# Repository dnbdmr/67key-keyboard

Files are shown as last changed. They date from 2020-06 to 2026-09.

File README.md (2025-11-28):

# A mechanical keyboard with a Thinkpad Trackpoint module installed

- Uses a trackpoint module from an old laptop keyboard. Some more details in hw/
- Uses Microchip SAMD21 MCU with TinyUSB
- Shift registers instead of key matrix

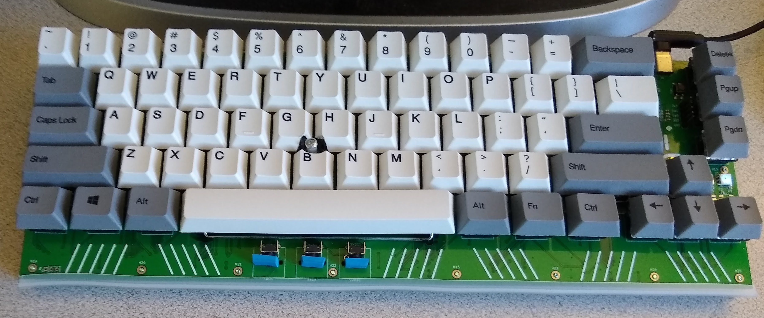
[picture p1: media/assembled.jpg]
Assembled picture


[Schematic](media/67keys-trackpoint.pdf)

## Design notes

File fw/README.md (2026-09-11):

# 67 Key keyboard with trackpoint

- Uses with uf2-samdx1 bootloader. Linker screipt offsetx by 0x2000. https://github.com/dnbdmr/uf2-samdx1

## TODO

- [ ] Finish keymap/layers
- [ ] Make tp reset non blocking?
- [ ] uf2: turn down brightness on rgbs
  tud\_descriptor\_string\_cb
- [ ] Merge spi master and matrix?
- [ ] Make force reset universal
- [ ] Turn off unused clocks? APB ADC. Whatever was started by uf2
- [ ] Figure out clean way to have keys do things outside of keymap
- [ ] Set up Fn lock
- [ ] Make menu/help, move to config.c?
- [ ] Intermittent wake up from sleep after putting computer to sleep.
- [ ] implement idle rate switch
- [x] Set serial number in descriptor? check uf2 source. add to
  wake up computer.
- [x] sends 3 reports whenever any key changes. problem?
- [x] limit scrolling to 1 at a time.
- [x] Check speedup of inlining millis(). Doesn't reallly work with externs.
  Cleared the dmb/irq around returning msticks, increased 108k->112kHz.
- [x] Implement debounce? Does happen occasionally.
- [x] tp reading and writing from ram stalls sometimes. dataAvailable not being
set? Done, set up timeout in tp\_getDataBit().
- [x] Wakeup from TP and spacebar working, with idle(1). Standby not working, must
set up low level interrupt and clocks. Linux not setting wakeup enabled by
default, works when changed. Must be hid only? Added udev rule from archwiki.
Changed HID portocol to keyboard in hid descriptor. Wakeup enabled without udev
rule
- [x] set up modifier reporting
- [x] set up system for leds
- [x] Delay a bit after middle mouse to make sure it's not a scroll. Do like tp
wired keyboard, only send middle button on release? Done, hardcoded dirtily.

## Power and Sleep

The trackpoint uses an external interrupt on the falling edge to clock in data.
There is also a line going straight to the space bar, set up to interrupt on a
low level. Level interrupts are asynchronout and can wake up from deep sleep.
These are both configured in trackpoint.c. So, to go to sleep, I set tp clk pin
to trigger on a low level and enable the spacebar interrupt. Immediately on wake
up (or first call) I turn off the spacebar interrupt and reset the tp clk pin to
a falling edge interrupt.

Waking up from sleep has been a little tricky. Entering deep sleep works. Waking
up from a low level external interrupt also works. But, waking up from a usb
resume does not start up correctly. The current draw spikes, then drops back
down. So, I'm using idle(2). Sleeps and wakes up fine.

- Deep sleep with Trackpoint:	13.5mA
- Deep sleep w/o Trackpoint:	1.1mA
- Idle(2) with Trackpoint:		17.5mA
- Normal with LEDs:				26mA

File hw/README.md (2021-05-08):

# 67 key Keyboard with trackpoint

__Hardware__
- 25x Splined Press-Fit Threaded Standoffs with Open End, Miniature, 3.2mm OD, 3mm Long. McMaster 92985A818. $4.12
- 25x Steel Pan Head Phillips Screw, M2 x 0.4 mm Thread, 10 mm Long. McMaster 92005A033. $4.14
- 25x Nylon Unthreaded Spacers, 1/4" OD, 1/4" Long, Black. McMaster 90176A133.
- 1x	Nylon Unthreaded Spacer, 4.5 mm OD, 20 mm Long, for M3 Screw Size. For Trackpoint. McMaster 93657A223
- 1"	Foam Mounting Tape, Repositionable, 1" Wide, 15 Feet Long, 0.0338" Overall Thickness. For Trackpoint. McMaster 8117A25
- 5x	Adhesive back bumpers. $4.22
- 5x	Adhesive back bumpers. $7.90

__TODO REV B__
- [ ] More testpoints
- [ ] labels on test points
- [ ] Label keys per qwerty
- [ ] High side FET to power off dotstars? Same for trackpoint? Can't get to USB suspend 2.5mA.

__REV A PROBLEMS__
- [ ] Switch 3V3 and ground planes?
- [ ] pin headers: put pin 1 on gnd
- [ ] Shift register outputs are all inverted. Should only be inverted on final register.
- [ ] Top board holes need to be 3.2mm for mini standoff, used a 3.1mm drill bit.
- [ ] Not enough clearance around mounting hardware. Especially spacers.

__TODO REV A__
- [x] figure out mounting between boards
- [x] More drawings?
- [x] APA102 placement?
- [x] make bottom mounting board
- [x] make tp footprint and mount
- [x] add mounting holes all over
- [x] verify tp pinout and wiring
- [x] add redundant buttons for mouse
- [x] adjust designators?
- [x] change tp conn to top contact?

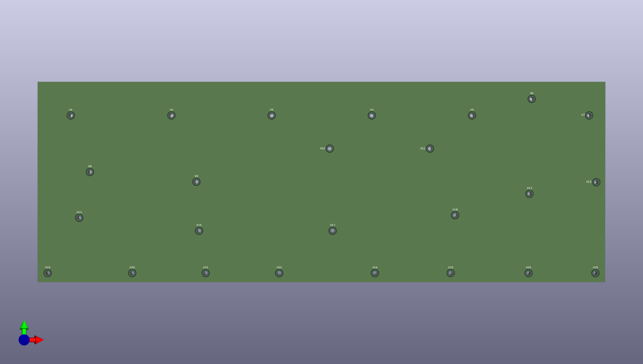
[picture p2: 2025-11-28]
media/67keys-trackpoint_back_board.png

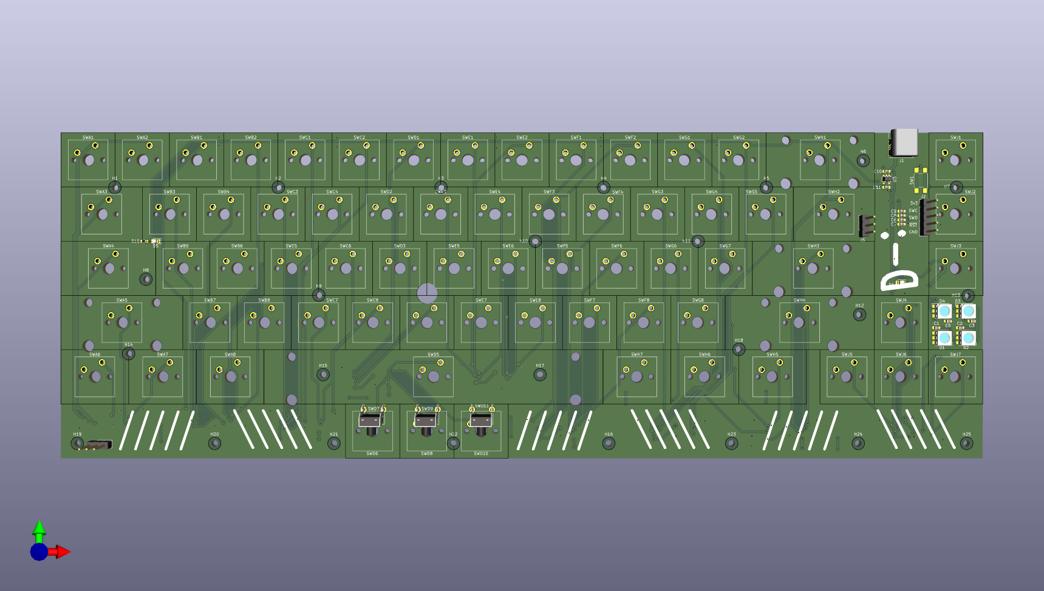
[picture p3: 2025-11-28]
media/67keys-trackpoint_pcb_f.png

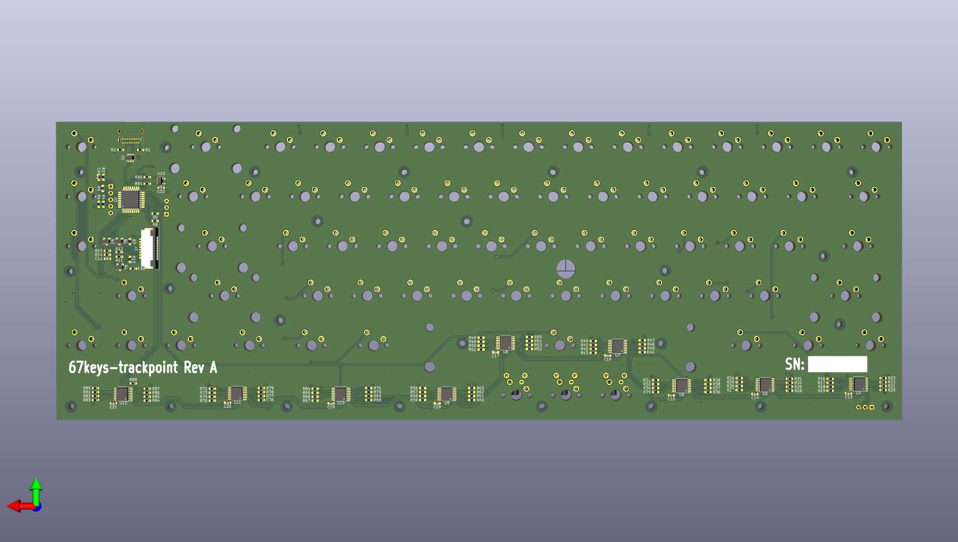
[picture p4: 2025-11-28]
media/67keys-trackpoint_pcb_b.png

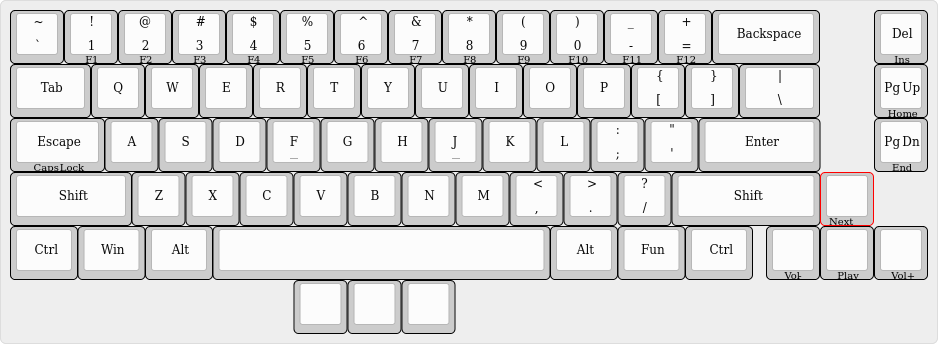
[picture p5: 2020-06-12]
hw/layout/keyboard-layout.png

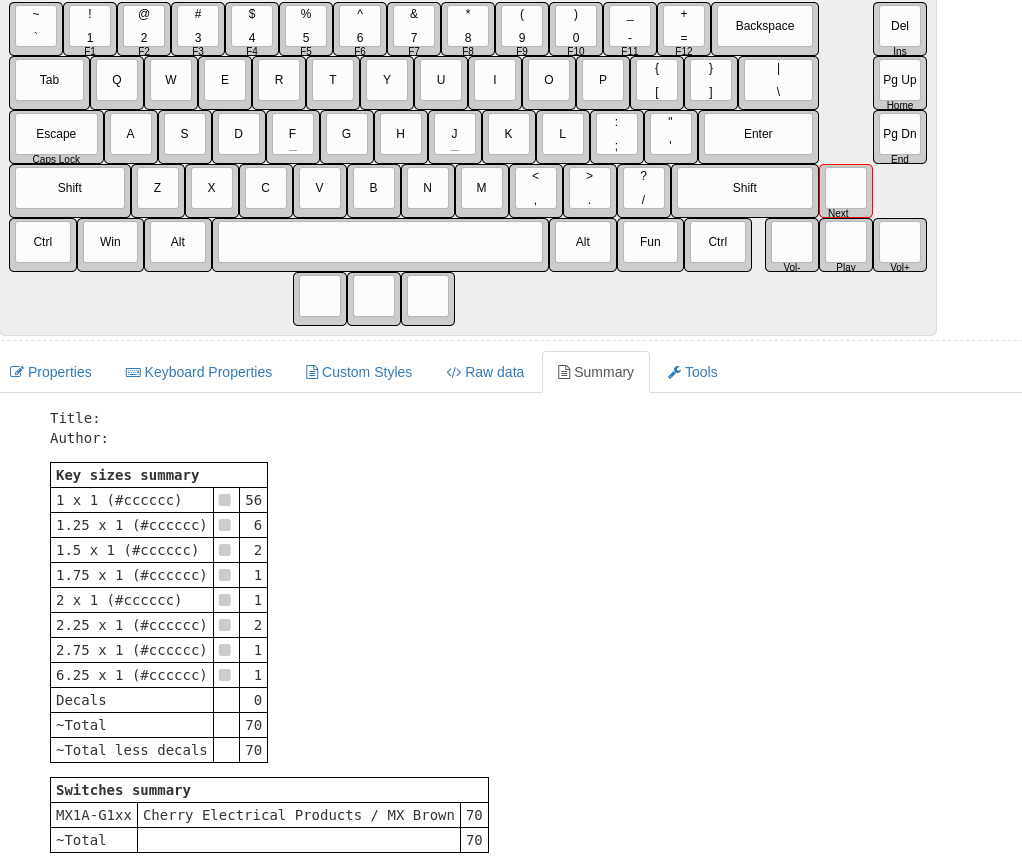
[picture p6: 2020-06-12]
hw/layout/keyboard-layout_details.png

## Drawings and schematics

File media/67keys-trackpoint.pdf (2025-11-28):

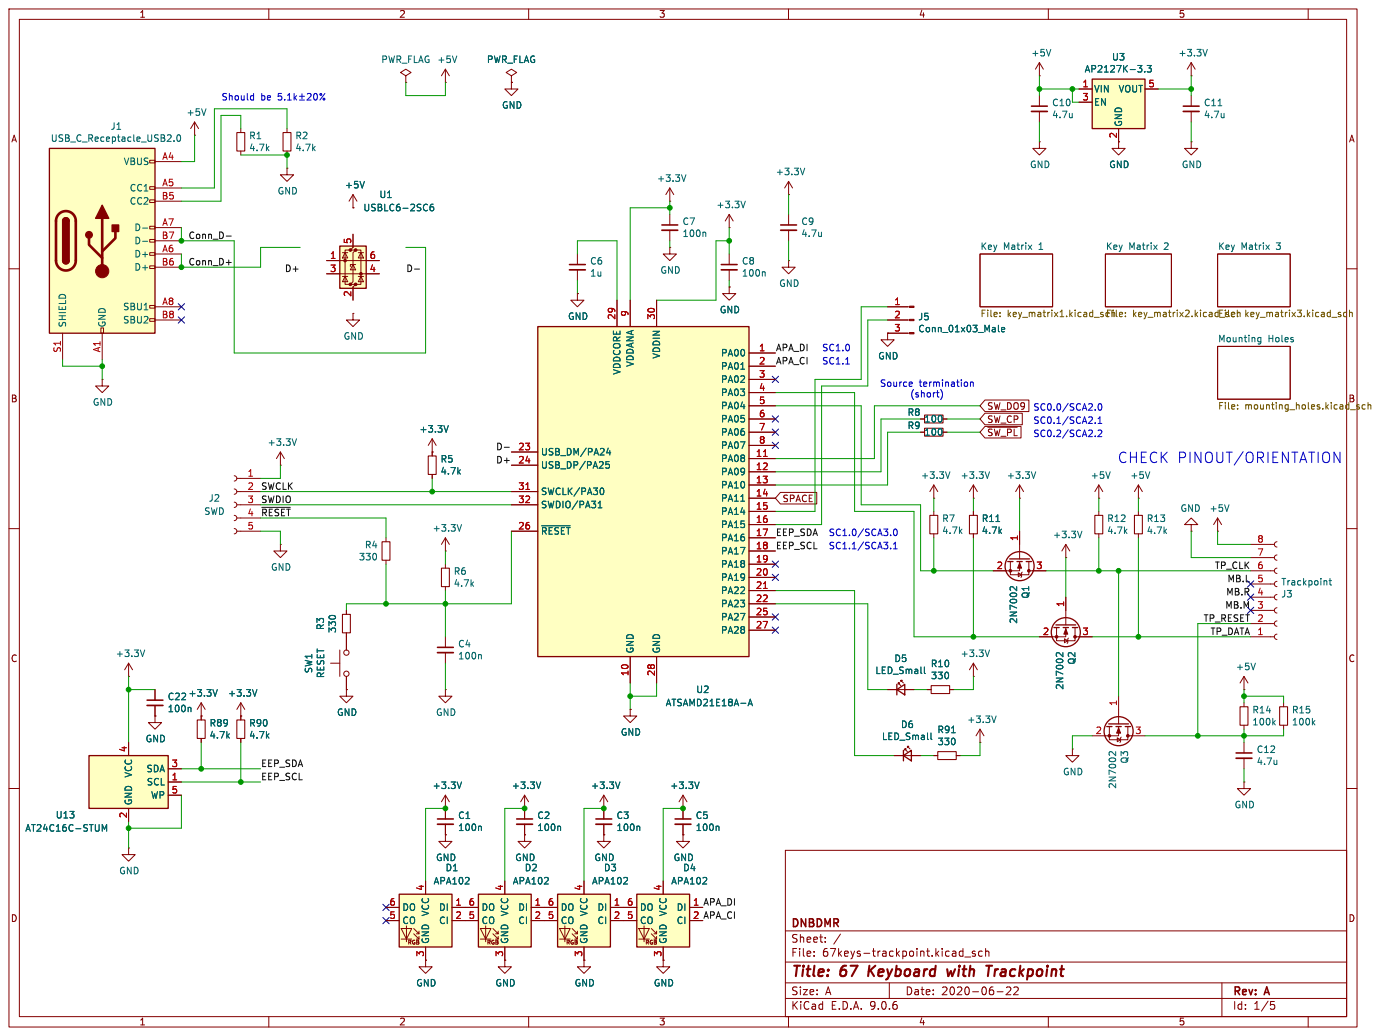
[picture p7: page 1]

9 GND 10 VDDCORE 29 USB_DM/PA24 23 USB_DP/PA25 24 SWCLK/PA30 31 SWDIO/PA31 32 ~{RESET} 26 U2 ATSAMD21E18A-A GND

9 GND 10 VDDCORE 29 USB_DM/PA24 23 USB_DP/PA25 24 SWCLK/PA30 31 SWDIO/PA31 32 ~{RESET} 26 GND

2 SDA 3 SCL 1 WP 5 U13 AT24C16C-STUM

3 DO 6 CO 5 D4 APA102 GND GND

3 DO 6 CO 5 D3 APA102 GND GND

3 DO 6 CO 5 GND GND

3 DO 6 CO 5 D1 APA102 GND GND

Id: 1/5 Title: 67 Keyboard with Trackpoint File: 67keys-trackpoint.kicad_sch Sheet: / DNBDMR

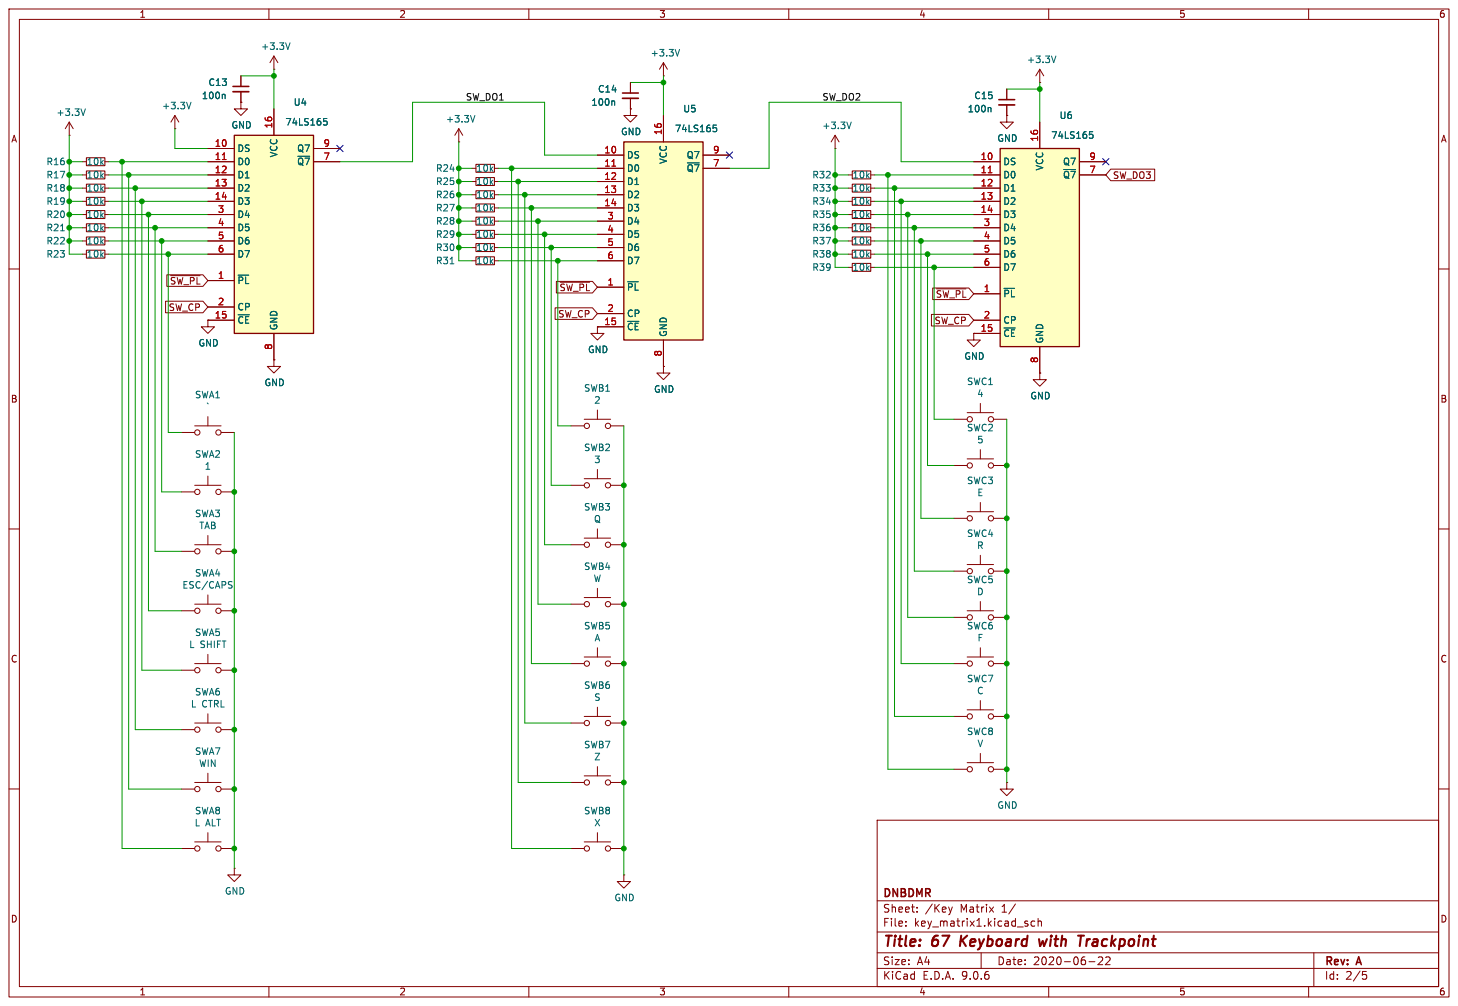
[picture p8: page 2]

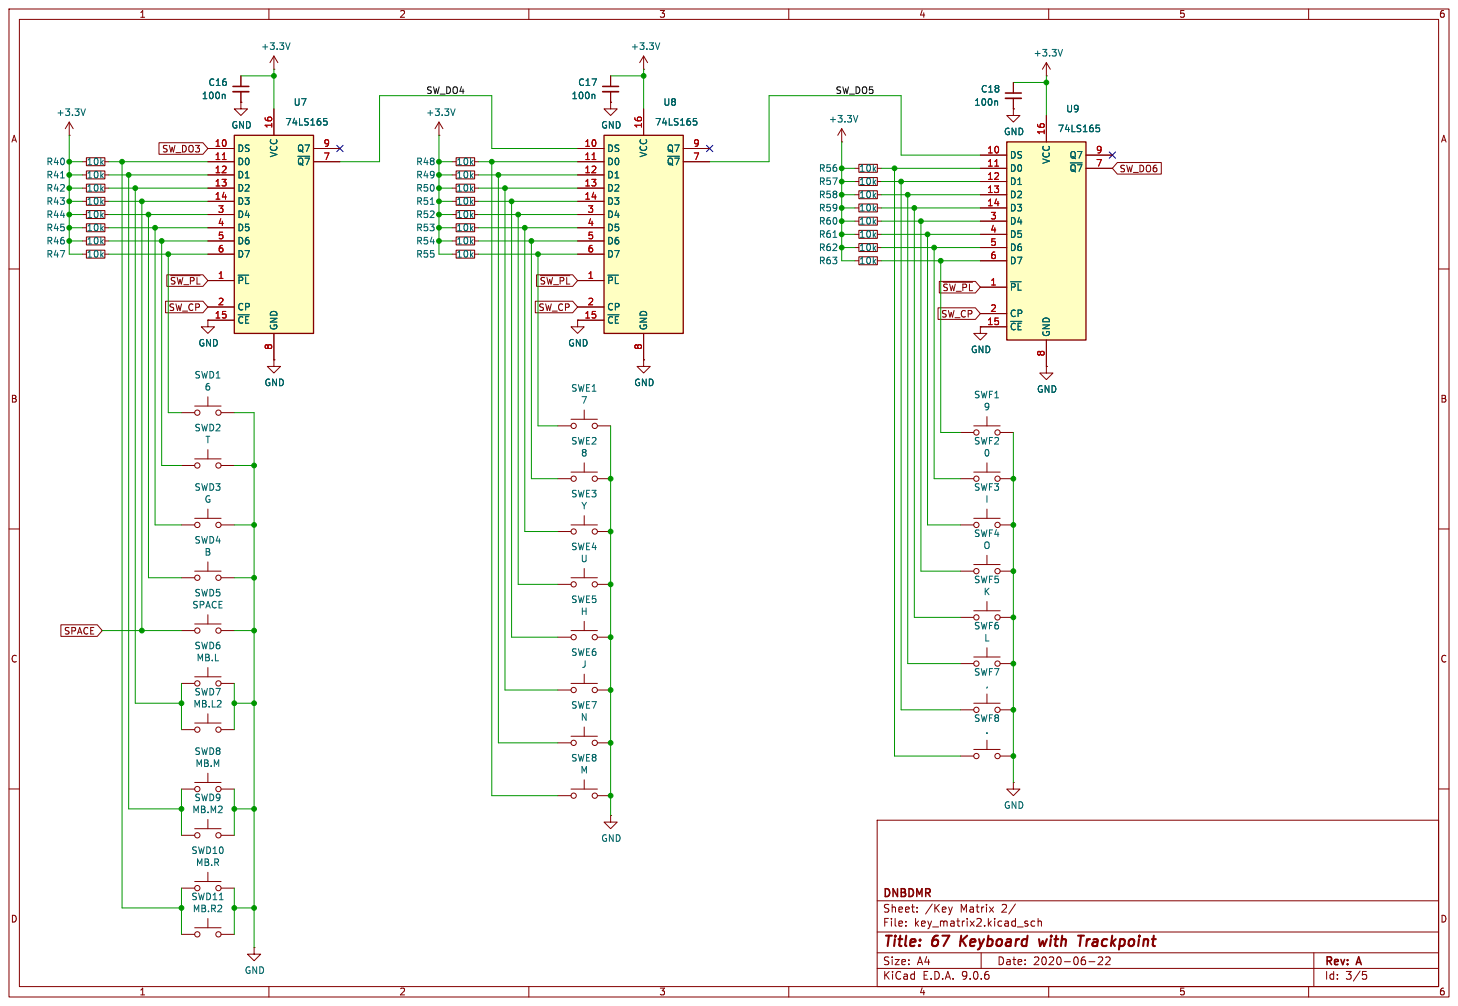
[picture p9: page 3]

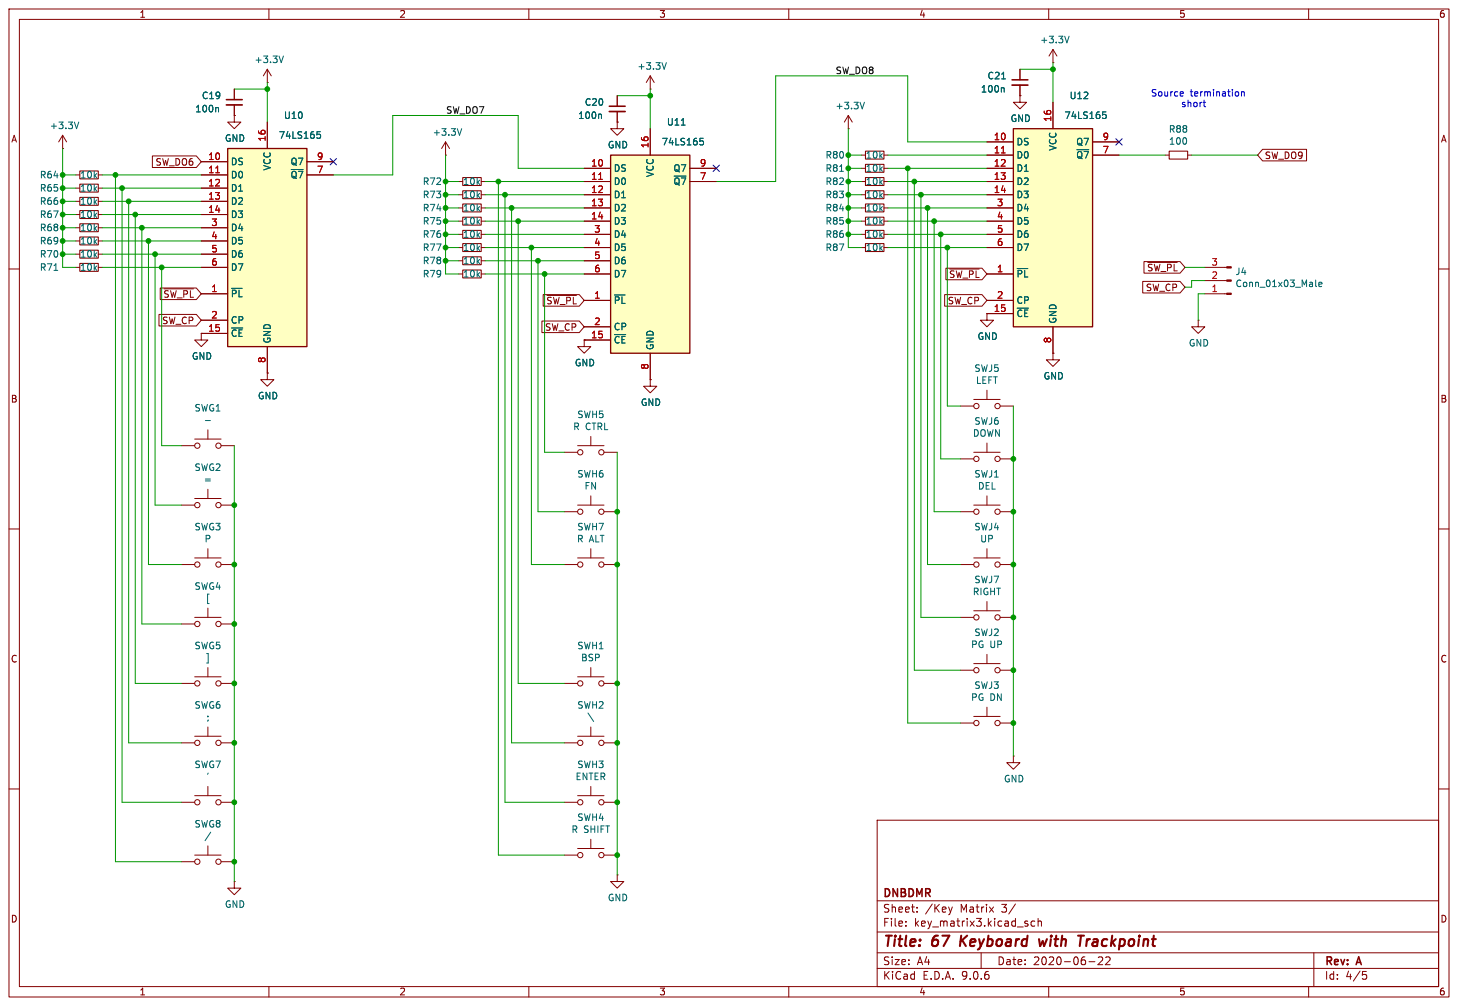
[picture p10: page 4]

8 Q7 9 ~{Q7} 7 GND GND GND GND

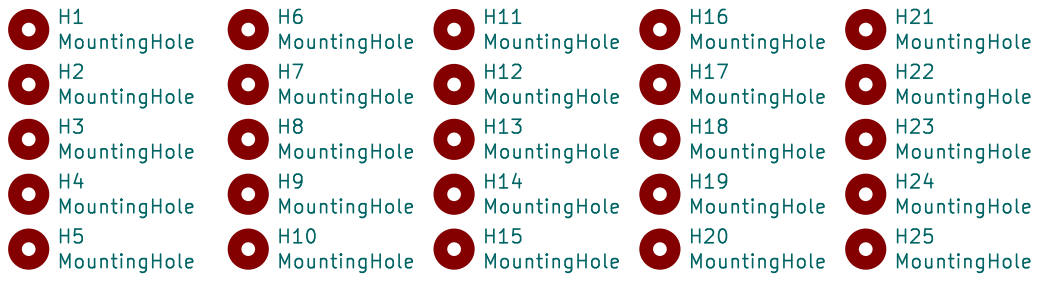
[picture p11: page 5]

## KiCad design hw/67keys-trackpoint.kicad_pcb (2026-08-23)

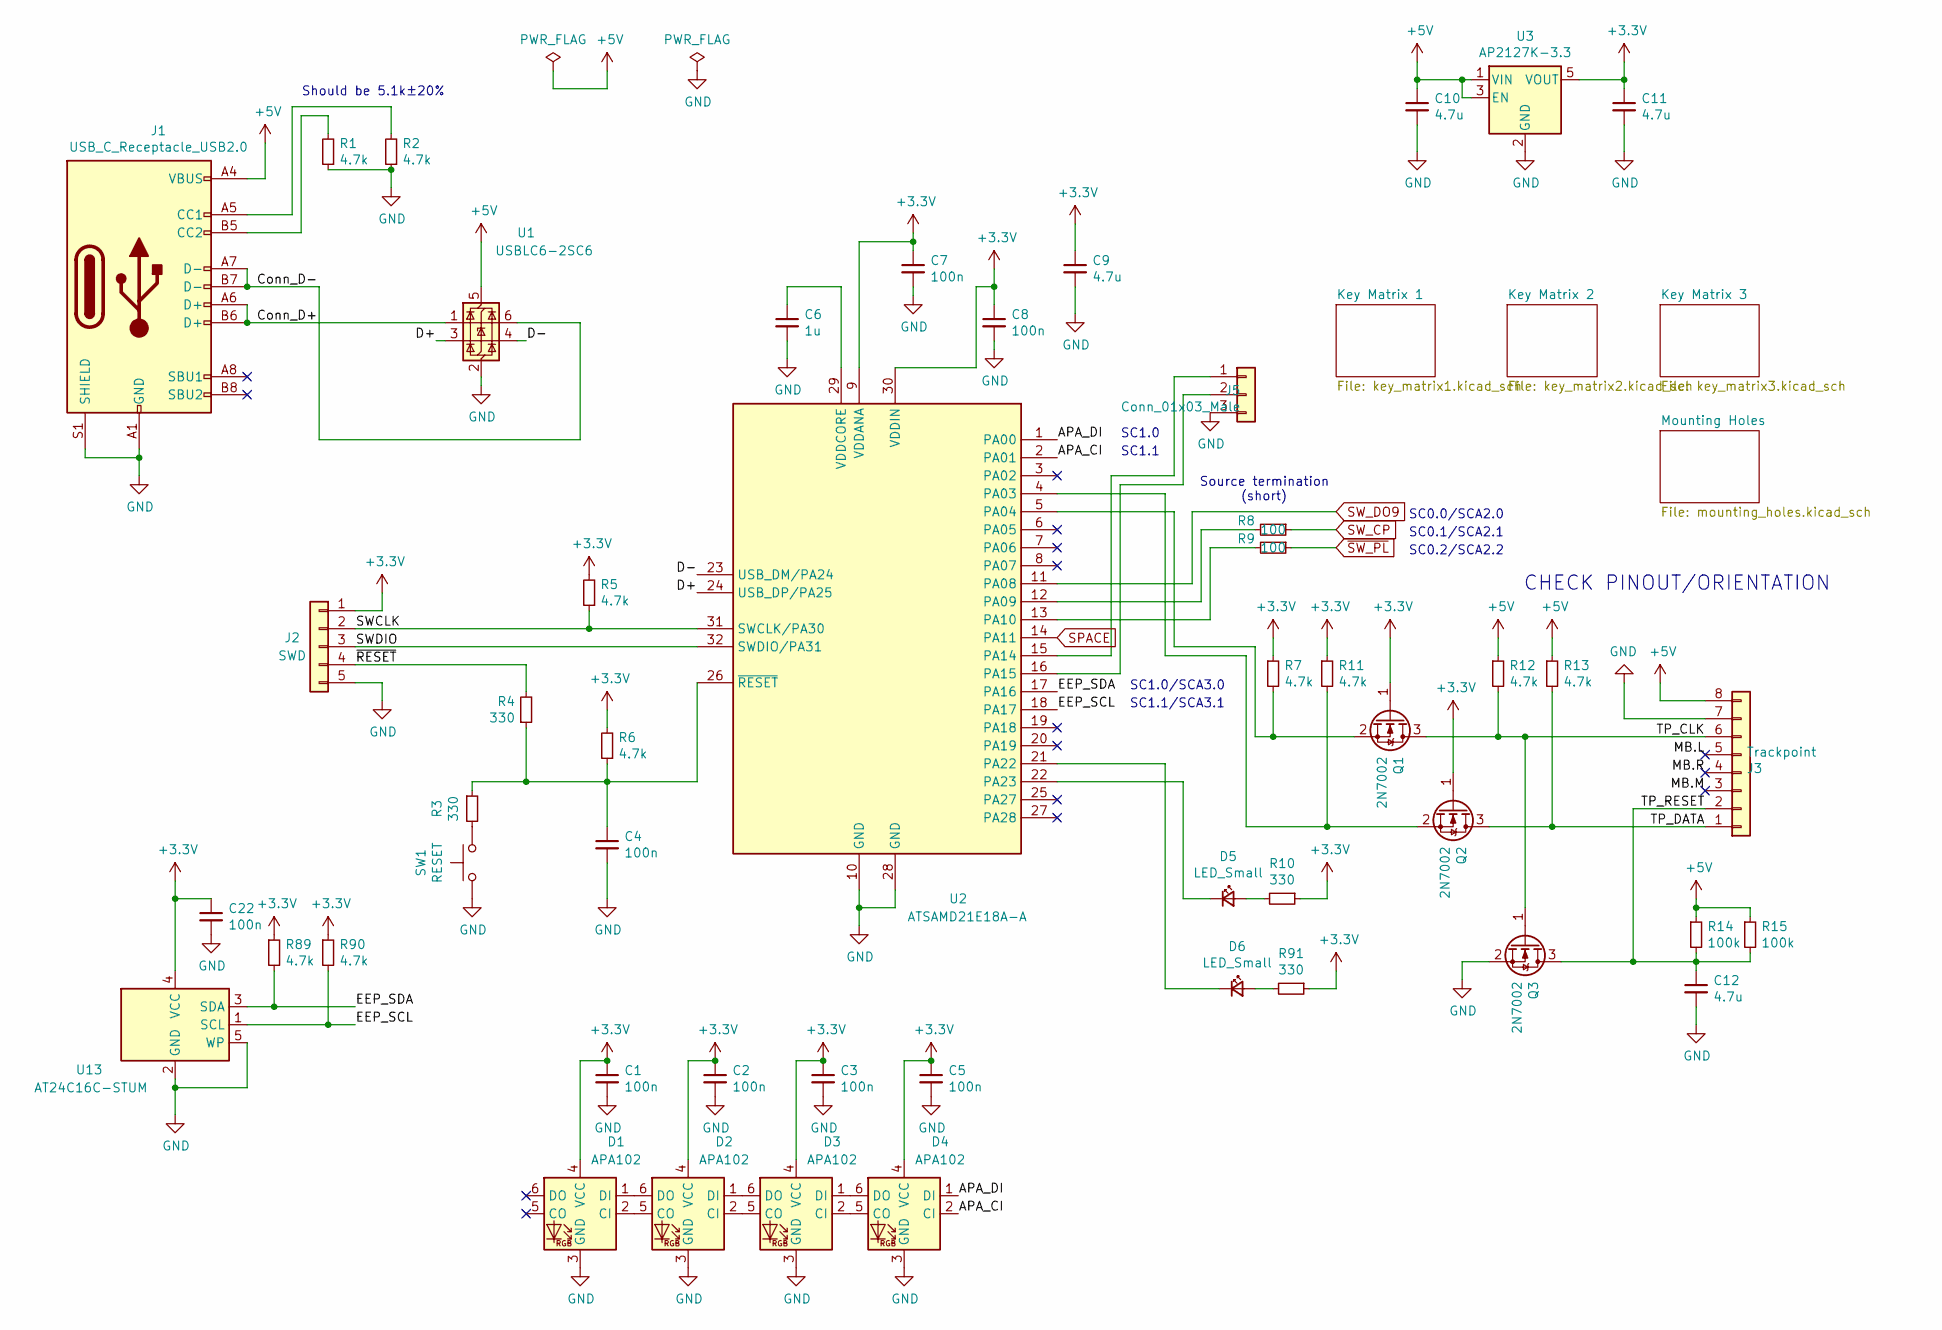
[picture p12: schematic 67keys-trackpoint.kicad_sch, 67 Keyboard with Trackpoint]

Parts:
C1, C2, C3, C4, C5, C7, C8, C22: 100n; C_0603_1608Metric_Pad1.08x0.95mm_HandSolder
C6: 1u; C_0603_1608Metric_Pad1.08x0.95mm_HandSolder
C9, C10, C11, C12: 4.7u; C_0603_1608Metric_Pad1.08x0.95mm_HandSolder
D1, D2, D3, D4: APA102; LED_RGB_5050-6
D5, D6: LED_Small; LED_0805_2012Metric_Pad1.15x1.40mm_HandSolder
J1: USB_C_Receptacle_USB2.0; USB_C_Receptacle_GCT_USB4085
J2: SWD; PinHeader_1x05_P2.54mm_Vertical
J3: Trackpoint; TE_84952-8_1x08-1MP_P1.0mm_Horizontal
J5: Conn_01x03_Male; PinHeader_1x03_P2.54mm_Vertical
Q1, Q2, Q3: 2N7002; SOT-23
R1, R2, R5, R6, R7, R11, R12, R13, R89, R90: 4.7k; R_0603_1608Metric_Pad0.98x0.95mm_HandSolder
R3, R4, R10, R91: 330; R_0603_1608Metric_Pad0.98x0.95mm_HandSolder
R8, R9: 100; R_0603_1608Metric_Pad0.98x0.95mm_HandSolder
R14, R15: 100k; R_0603_1608Metric_Pad0.98x0.95mm_HandSolder
SW1: RESET; SW_SPST_TL3305A
U1: USBLC6-2SC6; SOT-23-6
U2: ATSAMD21E18A-A; TQFP-32_7x7mm_P0.8mm
U3: AP2127K-3.3; SOT-23-5
U13: AT24C16C-STUM; SOT-23-5

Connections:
+3V3: C1.1, C2.1, C3.1, C5.1, C7.1, C8.1, C9.1, C11.1, C22.1, D1.4 (VCC), D2.4 (VCC), D3.4 (VCC), D4.4 (VCC), J2.1, Q1.1 (G), Q2.1 (G), R5.2, R6.2, R7.1, R10.1, R11.1, R89.1, R90.1, R91.1, U2.9 (VDDANA), U2.30 (VDDIN), U3.5 (VOUT), U13.4 (VCC); also elsewhere on the board
+5V: C10.1, J1.A4 (VBUS), J1.A9 (VBUS), J1.B4 (VBUS), J1.B9 (VBUS), J3.8, R12.1, R13.1, R14.1, R15.1, U1.5 (VBUS), U3.1 (VIN), U3.3 (EN)
/APA_CI: D4.2 (CI), U2.2 (PA01)
/APA_DI: D4.1 (DI), U2.1 (PA00)
/EEP_SCL: R90.2, U2.18 (PA17), U13.1 (SCL)
/EEP_SDA: R89.2, U2.17 (PA16), U13.3 (SDA)
/SWCLK: J2.2, R5.1, U2.31 (SWCLK/PA30)
/SWDIO: J2.3, U2.32 (SWDIO/PA31)
/TP_CLK: J3.6, Q1.3 (D), Q3.1 (G), R12.2
/TP_DATA: J3.1, Q2.3 (D), R13.2
/TP_RESET: C12.1, J3.2, Q3.3 (D), R14.2, R15.2
/~RESET: J2.4, R4.2
GND: C1.2, C2.2, C3.2, C4.2, C5.2, C6.2, C7.2, C8.2, C9.2, C10.2, C11.2, C12.2, C22.2, D1.3 (GND), D2.3 (GND), D3.3 (GND), D4.3 (GND), J1.A1 (GND), J1.A12 (GND), J1.B1 (GND), J1.B12 (GND), J1.S1 (SHIELD), J2.5, J3.7, J5.3, Q3.2 (S), R1.1, R2.1, SW1.1, U1.2 (GND), U2.10 (GND), U2.28 (GND), U3.2 (GND), U13.2 (GND), U13.5 (WP); also elsewhere on the board
unnamed: C4.1, R3.1, R4.1, R6.1, U2.26 (~RESET)
unnamed: C6.1, U2.29 (VDDCORE)
unnamed: D1.1 (DI), D2.6 (DO)
unnamed: D1.2 (CI), D2.5 (CO)
unnamed: D2.1 (DI), D3.6 (DO)
unnamed: D2.2 (CI), D3.5 (CO)
unnamed: D3.1 (DI), D4.6 (DO)
unnamed: D3.2 (CI), D4.5 (CO)
unnamed: D5.1 (K), U2.22 (PA23)
unnamed: D5.2 (A), R10.2
unnamed: D6.1 (K), U2.21 (PA22)
unnamed: D6.2 (A), R91.2
unnamed: J1.A5 (CC1), R2.2
unnamed: J1.B5 (CC2), R1.2
unnamed: J5.1, U2.15 (PA14)
unnamed: J5.2, U2.16 (PA15)
unnamed: Q1.2 (S), R7.2, U2.5 (PA04)
unnamed: Q2.2 (S), R11.2, U2.4 (PA03)
unnamed: R3.2, SW1.2
unnamed: R8.2, U2.12 (PA09)
unnamed: R9.2, U2.13 (PA10)
SPACE: U2.14 (PA11); also elsewhere on the board
SW_CP: R8.1; also elsewhere on the board
SW_DO9: U2.11 (PA08); also elsewhere on the board
~SW_PL: R9.1; also elsewhere on the board

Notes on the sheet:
SC1.0/SCA3.0
CHECK PINOUT/ORIENTATION
SC1.0
SC1.1
SC0.2/SCA2.2
SC0.0/SCA2.0
SC0.1/SCA2.1
SC1.1/SCA3.1
Should be 5.1k±20%
Source termination (short)

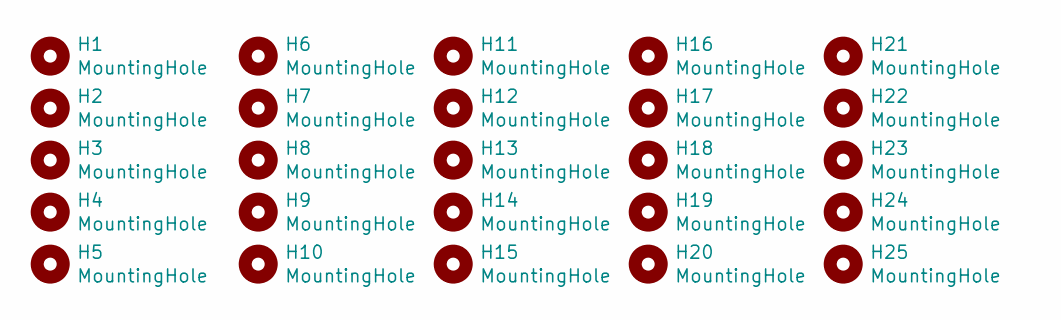
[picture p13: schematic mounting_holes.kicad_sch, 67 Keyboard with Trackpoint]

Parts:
H1, H2, H3, H4, H5, H6, H7, H8, H9, H10, H11, H12, H13, H14, H15, H16, H17, H18, H19, H20, H21, H22, H23, H24, H25: MountingHole; MountingHole_2.2mm_M2

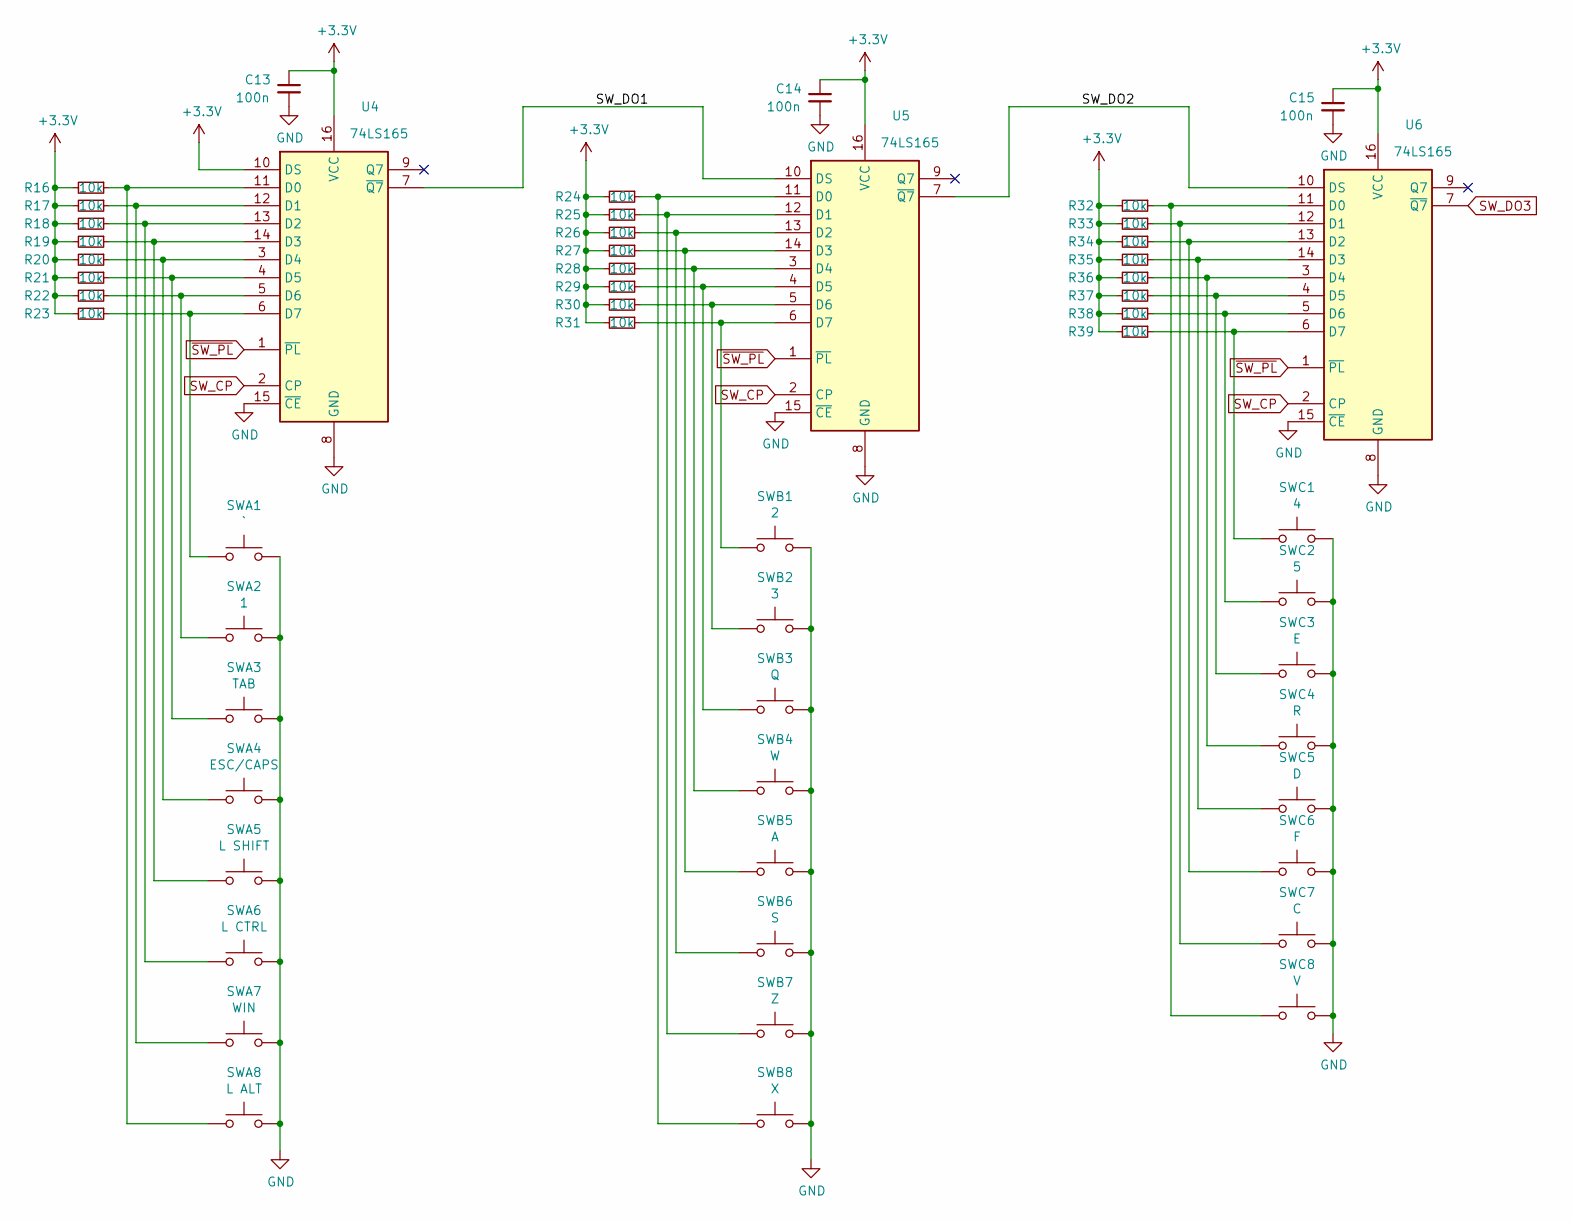
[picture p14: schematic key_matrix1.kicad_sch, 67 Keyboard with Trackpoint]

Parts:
C13, C14, C15: 100n; C_0603_1608Metric_Pad1.08x0.95mm_HandSolder
R16, R17, R18, R19, R20, R21, R22, R23, R24, R25, R26, R27, R28, R29, R30, R31, R32, R33, R34, R35, R36, R37, R38, R39: 10k; R_0603_1608Metric_Pad0.98x0.95mm_HandSolder
SWA1: `; SW_Cherry_MX_1.00u_PCB
SWA2: 1; SW_Cherry_MX_1.00u_PCB
SWA3: TAB; SW_Cherry_MX_1.50u_PCB
SWA4: ESC/CAPS; SW_Cherry_MX_1.75u_PCB
SWA5: L SHIFT; SW_Cherry_MX_2.25u_PCB
SWA6: L CTRL; SW_Cherry_MX_1.25u_PCB
SWA7: WIN; SW_Cherry_MX_1.25u_PCB
SWA8: L ALT; SW_Cherry_MX_1.25u_PCB
SWB1: 2; SW_Cherry_MX_1.00u_PCB
SWB2: 3; SW_Cherry_MX_1.00u_PCB
SWB3: Q; SW_Cherry_MX_1.00u_PCB
SWB4: W; SW_Cherry_MX_1.00u_PCB
SWB5: A; SW_Cherry_MX_1.00u_PCB
SWB6: S; SW_Cherry_MX_1.00u_PCB
SWB7: Z; SW_Cherry_MX_1.00u_PCB
SWB8: X; SW_Cherry_MX_1.00u_PCB
SWC1: 4; SW_Cherry_MX_1.00u_PCB
SWC2: 5; SW_Cherry_MX_1.00u_PCB
SWC3: E; SW_Cherry_MX_1.00u_PCB
SWC4: R; SW_Cherry_MX_1.00u_PCB
SWC5: D; SW_Cherry_MX_1.00u_PCB
SWC6: F; SW_Cherry_MX_1.00u_PCB
SWC7: C; SW_Cherry_MX_1.00u_PCB
SWC8: V; SW_Cherry_MX_1.00u_PCB
U4, U5, U6: 74LS165; TSSOP-16_4.4x5mm_P0.65mm

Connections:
+3V3: C13.1, C14.1, C15.1, R16.2, R17.2, R18.2, R19.2, R20.2, R21.2, R22.2, R23.2, R24.2, R25.2, R26.2, R27.2, R28.2, R29.2, R30.2, R31.2, R32.2, R33.2, R34.2, R35.2, R36.2, R37.2, R38.2, R39.2, U4.10 (DS), U4.16 (VCC), U5.16 (VCC), U6.16 (VCC); also elsewhere on the board
/Key Matrix 1/SW_DO1: U4.7 (~Q7), U5.10 (DS)
/Key Matrix 1/SW_DO2: U5.7 (~Q7), U6.10 (DS)
GND: C13.2, C14.2, C15.2, SWA1.2, SWA2.2, SWA3.2, SWA4.2, SWA5.2, SWA6.2, SWA7.2, SWA8.2, SWB1.2, SWB2.2, SWB3.2, SWB4.2, SWB5.2, SWB6.2, SWB7.2, SWB8.2, SWC1.2, SWC2.2, SWC3.2, SWC4.2, SWC5.2, SWC6.2, SWC7.2, SWC8.2, U4.8 (GND), U4.15 (~CE), U5.8 (GND), U5.15 (~CE), U6.8 (GND), U6.15 (~CE); also elsewhere on the board
unnamed: R16.1, SWA8.1, U4.11 (D0)
unnamed: R17.1, SWA7.1, U4.12 (D1)
unnamed: R18.1, SWA6.1, U4.13 (D2)
unnamed: R19.1, SWA5.1, U4.14 (D3)
unnamed: R20.1, SWA4.1, U4.3 (D4)
unnamed: R21.1, SWA3.1, U4.4 (D5)
unnamed: R22.1, SWA2.1, U4.5 (D6)
unnamed: R23.1, SWA1.1, U4.6 (D7)
unnamed: R24.1, SWB8.1, U5.11 (D0)
unnamed: R25.1, SWB7.1, U5.12 (D1)
unnamed: R26.1, SWB6.1, U5.13 (D2)
unnamed: R27.1, SWB5.1, U5.14 (D3)
unnamed: R28.1, SWB4.1, U5.3 (D4)
unnamed: R29.1, SWB3.1, U5.4 (D5)
unnamed: R30.1, SWB2.1, U5.5 (D6)
unnamed: R31.1, SWB1.1, U5.6 (D7)
unnamed: R32.1, SWC8.1, U6.11 (D0)
unnamed: R33.1, SWC7.1, U6.12 (D1)
unnamed: R34.1, SWC6.1, U6.13 (D2)
unnamed: R35.1, SWC5.1, U6.14 (D3)
unnamed: R36.1, SWC4.1, U6.3 (D4)
unnamed: R37.1, SWC3.1, U6.4 (D5)
unnamed: R38.1, SWC2.1, U6.5 (D6)
unnamed: R39.1, SWC1.1, U6.6 (D7)
SW_CP: U4.2 (CP), U5.2 (CP), U6.2 (CP); also elsewhere on the board
SW_DO3: U6.7 (~Q7); also elsewhere on the board
~SW_PL: U4.1 (~PL), U5.1 (~PL), U6.1 (~PL); also elsewhere on the board

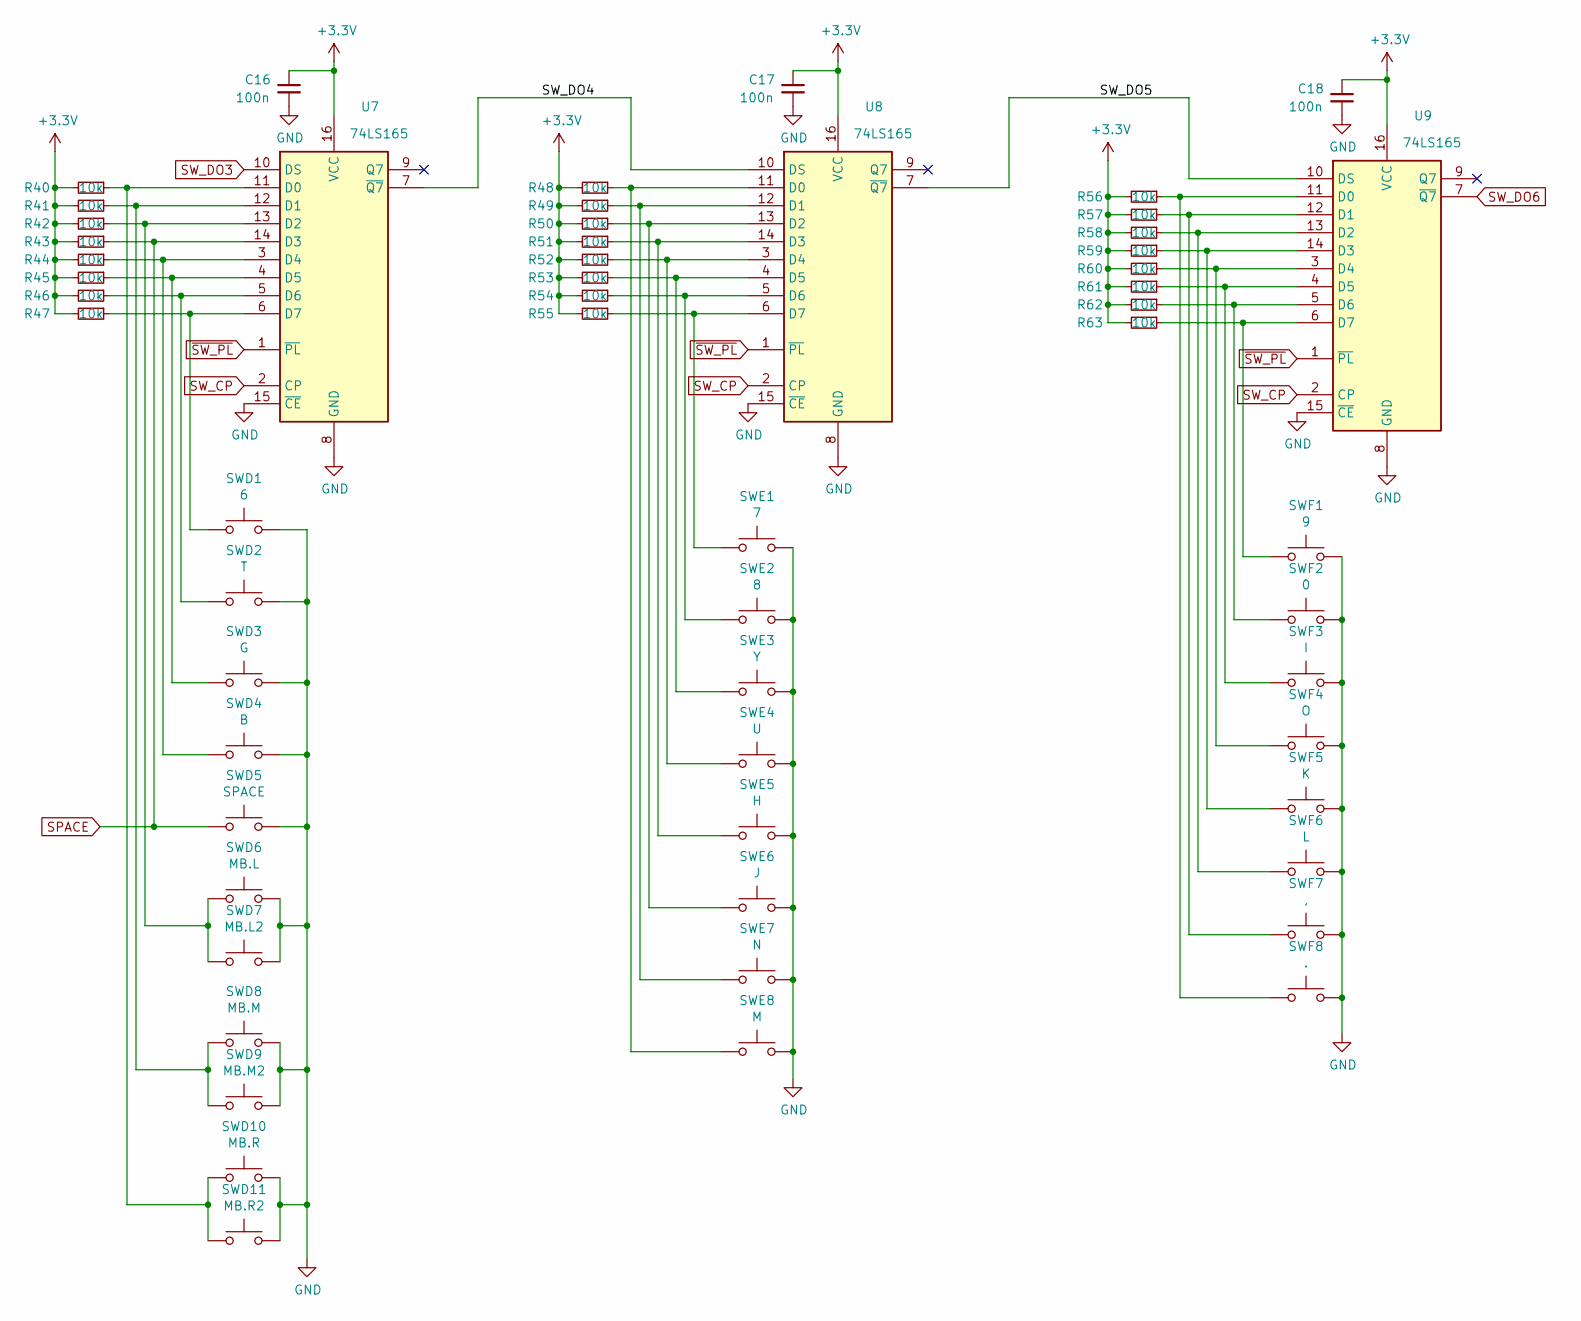
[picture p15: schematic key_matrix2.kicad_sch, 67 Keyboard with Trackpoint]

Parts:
C16, C17, C18: 100n; C_0603_1608Metric_Pad1.08x0.95mm_HandSolder
R40, R41, R42, R43, R44, R45, R46, R47, R48, R49, R50, R51, R52, R53, R54, R55, R56, R57, R58, R59, R60, R61, R62, R63: 10k; R_0603_1608Metric_Pad0.98x0.95mm_HandSolder
SWD1: 6; SW_Cherry_MX_1.00u_PCB
SWD2: T; SW_Cherry_MX_1.00u_PCB
SWD3: G; SW_Cherry_MX_1.00u_PCB
SWD4: B; SW_Cherry_MX_1.00u_PCB
SWD5: SPACE; SW_Cherry_MX_6.25u_PCB
SWD6: MB.L; SW_Cherry_MX_1.00u_PCB
SWD7: MB.L2; SW_Tactile_SPST_Angled_PTS645Vx58-2LFS
SWD8: MB.M; SW_Cherry_MX_1.00u_PCB
SWD9: MB.M2; SW_Tactile_SPST_Angled_PTS645Vx58-2LFS
SWD10: MB.R; SW_Cherry_MX_1.00u_PCB
SWD11: MB.R2; SW_Tactile_SPST_Angled_PTS645Vx58-2LFS
SWE1: 7; SW_Cherry_MX_1.00u_PCB
SWE2: 8; SW_Cherry_MX_1.00u_PCB
SWE3: Y; SW_Cherry_MX_1.00u_PCB
SWE4: U; SW_Cherry_MX_1.00u_PCB
SWE5: H; SW_Cherry_MX_1.00u_PCB
SWE6: J; SW_Cherry_MX_1.00u_PCB
SWE7: N; SW_Cherry_MX_1.00u_PCB
SWE8: M; SW_Cherry_MX_1.00u_PCB
SWF1: 9; SW_Cherry_MX_1.00u_PCB
SWF2: 0; SW_Cherry_MX_1.00u_PCB
SWF3: I; SW_Cherry_MX_1.00u_PCB
SWF4: O; SW_Cherry_MX_1.00u_PCB
SWF5: K; SW_Cherry_MX_1.00u_PCB
SWF6: L; SW_Cherry_MX_1.00u_PCB
SWF7: ,; SW_Cherry_MX_1.00u_PCB
SWF8: .; SW_Cherry_MX_1.00u_PCB
U7, U8, U9: 74LS165; TSSOP-16_4.4x5mm_P0.65mm

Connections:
+3V3: C16.1, C17.1, C18.1, R40.2, R41.2, R42.2, R43.2, R44.2, R45.2, R46.2, R47.2, R48.2, R49.2, R50.2, R51.2, R52.2, R53.2, R54.2, R55.2, R56.2, R57.2, R58.2, R59.2, R60.2, R61.2, R62.2, R63.2, U7.16 (VCC), U8.16 (VCC), U9.16 (VCC); also elsewhere on the board
/Key Matrix 2/SW_DO4: U7.7 (~Q7), U8.10 (DS)
/Key Matrix 2/SW_DO5: U8.7 (~Q7), U9.10 (DS)
GND: C16.2, C17.2, C18.2, SWD1.2, SWD2.2, SWD3.2, SWD4.2, SWD5.2, SWD6.2, SWD7.2, SWD8.2, SWD9.2, SWD10.2, SWD11.2, SWE1.2, SWE2.2, SWE3.2, SWE4.2, SWE5.2, SWE6.2, SWE7.2, SWE8.2, SWF1.2, SWF2.2, SWF3.2, SWF4.2, SWF5.2, SWF6.2, SWF7.2, SWF8.2, U7.8 (GND), U7.15 (~CE), U8.8 (GND), U8.15 (~CE), U9.8 (GND), U9.15 (~CE); also elsewhere on the board
unnamed: R40.1, SWD10.1, SWD11.1, U7.11 (D0)
unnamed: R41.1, SWD8.1, SWD9.1, U7.12 (D1)
unnamed: R42.1, SWD6.1, SWD7.1, U7.13 (D2)
unnamed: R44.1, SWD4.1, U7.3 (D4)
unnamed: R45.1, SWD3.1, U7.4 (D5)
unnamed: R46.1, SWD2.1, U7.5 (D6)
unnamed: R47.1, SWD1.1, U7.6 (D7)
unnamed: R48.1, SWE8.1, U8.11 (D0)
unnamed: R49.1, SWE7.1, U8.12 (D1)
unnamed: R50.1, SWE6.1, U8.13 (D2)
unnamed: R51.1, SWE5.1, U8.14 (D3)
unnamed: R52.1, SWE4.1, U8.3 (D4)
unnamed: R53.1, SWE3.1, U8.4 (D5)
unnamed: R54.1, SWE2.1, U8.5 (D6)
unnamed: R55.1, SWE1.1, U8.6 (D7)
unnamed: R56.1, SWF8.1, U9.11 (D0)
unnamed: R57.1, SWF7.1, U9.12 (D1)
unnamed: R58.1, SWF6.1, U9.13 (D2)
unnamed: R59.1, SWF5.1, U9.14 (D3)
unnamed: R60.1, SWF4.1, U9.3 (D4)
unnamed: R61.1, SWF3.1, U9.4 (D5)
unnamed: R62.1, SWF2.1, U9.5 (D6)
unnamed: R63.1, SWF1.1, U9.6 (D7)
SPACE: R43.1, SWD5.1, U7.14 (D3); also elsewhere on the board
SW_CP: U7.2 (CP), U8.2 (CP), U9.2 (CP); also elsewhere on the board
SW_DO3: U7.10 (DS); also elsewhere on the board
SW_DO6: U9.7 (~Q7); also elsewhere on the board
~SW_PL: U7.1 (~PL), U8.1 (~PL), U9.1 (~PL); also elsewhere on the board

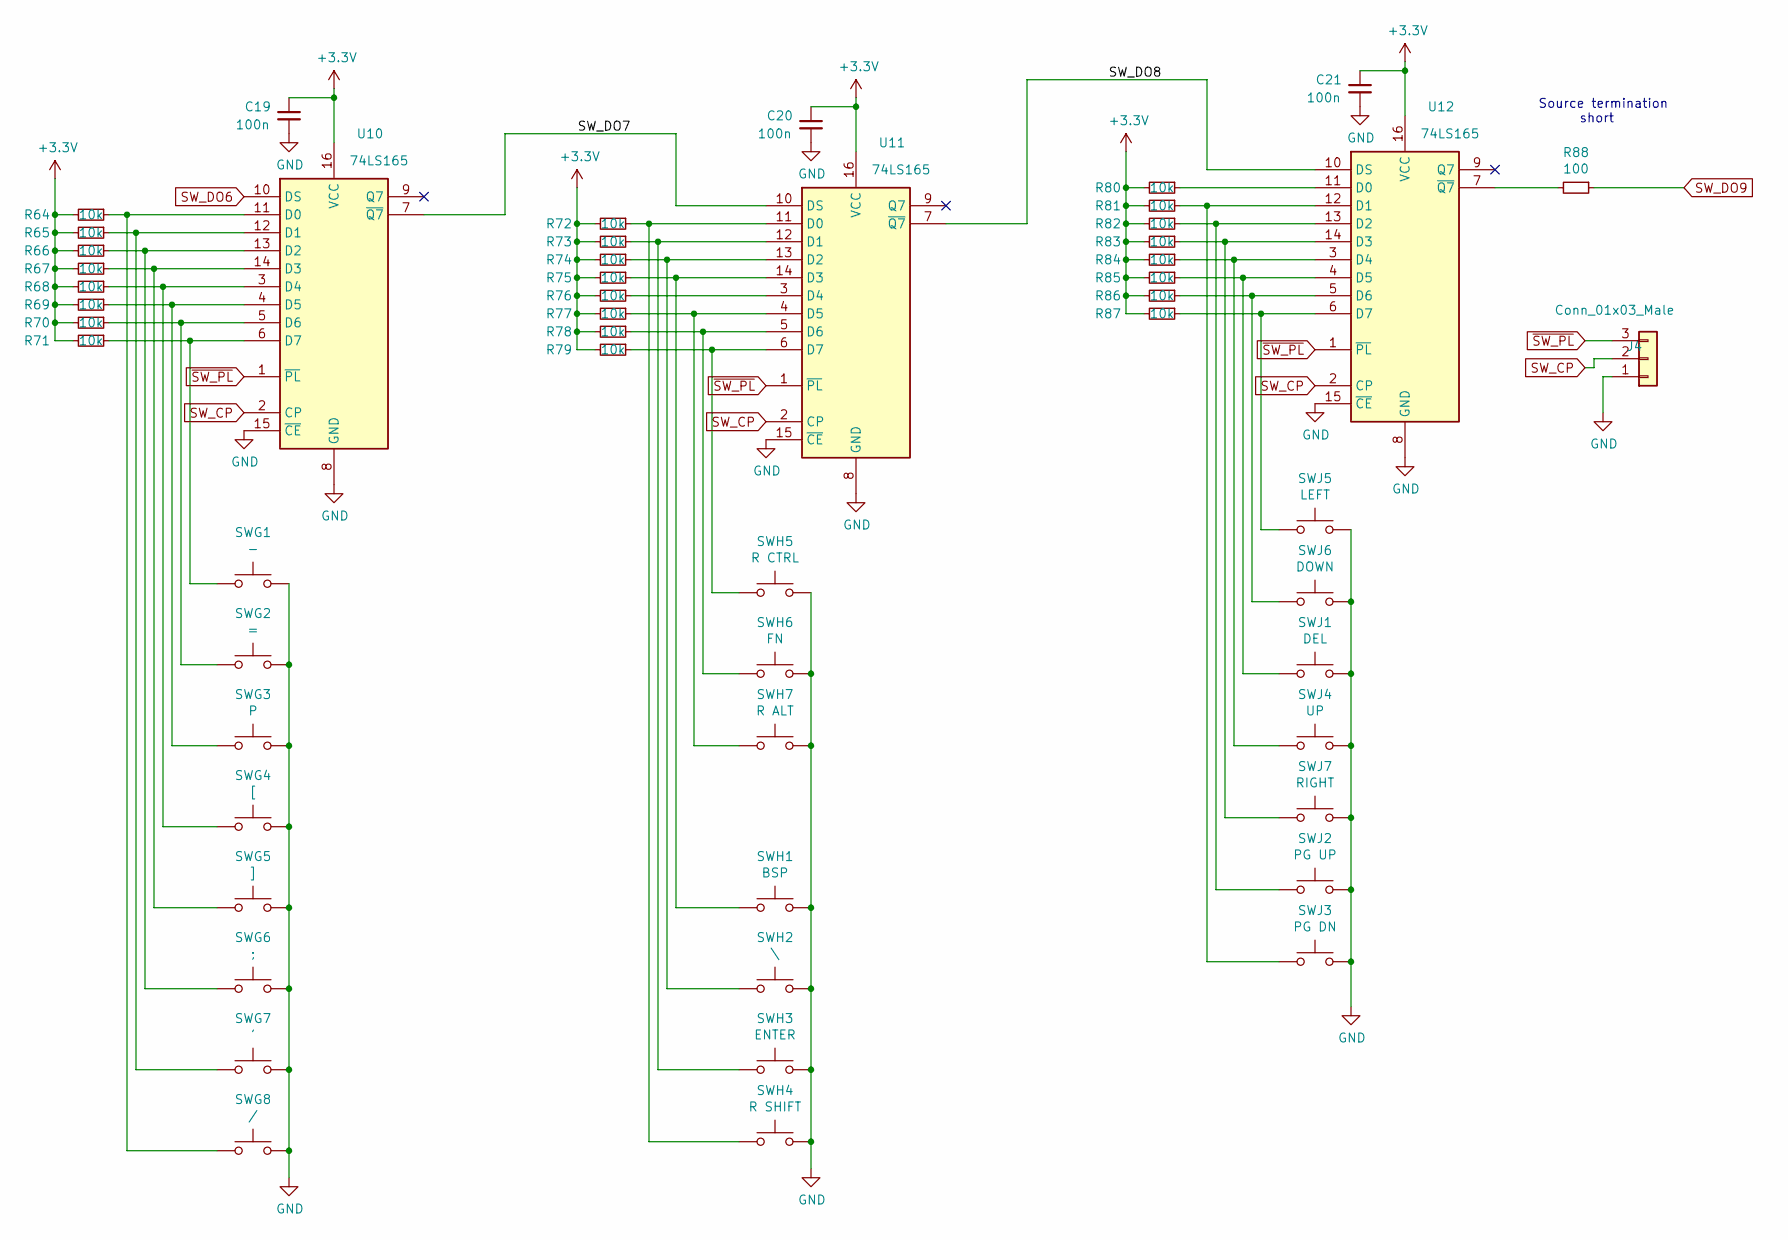
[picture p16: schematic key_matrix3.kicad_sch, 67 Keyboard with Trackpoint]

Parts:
C19, C20, C21: 100n; C_0603_1608Metric_Pad1.08x0.95mm_HandSolder
J4: Conn_01x03_Male; PinHeader_1x03_P2.54mm_Vertical
R64, R65, R66, R67, R68, R69, R70, R71, R72, R73, R74, R75, R76, R77, R78, R79, R80, R81, R82, R83, R84, R85, R86, R87: 10k; R_0603_1608Metric_Pad0.98x0.95mm_HandSolder
R88: 100; R_0603_1608Metric_Pad0.98x0.95mm_HandSolder
SWG1: -; SW_Cherry_MX_1.00u_PCB
SWG2: =; SW_Cherry_MX_1.00u_PCB
SWG3: P; SW_Cherry_MX_1.00u_PCB
SWG4: [; SW_Cherry_MX_1.00u_PCB
SWG5: ]; SW_Cherry_MX_1.00u_PCB
SWG6: ;; SW_Cherry_MX_1.00u_PCB
SWG7: '; SW_Cherry_MX_1.00u_PCB
SWG8: /; SW_Cherry_MX_1.00u_PCB
SWH1: BSP; SW_Cherry_MX_2.00u_PCB
SWH2: \; SW_Cherry_MX_1.50u_PCB
SWH3: ENTER; SW_Cherry_MX_2.25u_PCB
SWH4: R SHIFT; SW_Cherry_MX_2.75u_PCB
SWH5: R CTRL; SW_Cherry_MX_1.25u_PCB
SWH6: FN; SW_Cherry_MX_1.25u_PCB
SWH7: R ALT; SW_Cherry_MX_1.25u_PCB
SWJ1: DEL; SW_Cherry_MX_1.00u_PCB
SWJ2: PG UP; SW_Cherry_MX_1.00u_PCB
SWJ3: PG DN; SW_Cherry_MX_1.00u_PCB
SWJ4: UP; SW_Cherry_MX_1.00u_PCB
SWJ5: LEFT; SW_Cherry_MX_1.00u_PCB
SWJ6: DOWN; SW_Cherry_MX_1.00u_PCB
SWJ7: RIGHT; SW_Cherry_MX_1.00u_PCB
U10, U11, U12: 74LS165; TSSOP-16_4.4x5mm_P0.65mm

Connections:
+3V3: C19.1, C20.1, C21.1, R64.2, R65.2, R66.2, R67.2, R68.2, R69.2, R70.2, R71.2, R72.2, R73.2, R74.2, R75.2, R76.2, R77.2, R78.2, R79.2, R80.2, R81.2, R82.2, R83.2, R84.2, R85.2, R86.2, R87.2, U10.16 (VCC), U11.16 (VCC), U12.16 (VCC); also elsewhere on the board
/Key Matrix 3/SW_DO7: U10.7 (~Q7), U11.10 (DS)
/Key Matrix 3/SW_DO8: U11.7 (~Q7), U12.10 (DS)
GND: C19.2, C20.2, C21.2, J4.1, SWG1.2, SWG2.2, SWG3.2, SWG4.2, SWG5.2, SWG6.2, SWG7.2, SWG8.2, SWH1.2, SWH2.2, SWH3.2, SWH4.2, SWH5.2, SWH6.2, SWH7.2, SWJ1.2, SWJ2.2, SWJ3.2, SWJ4.2, SWJ5.2, SWJ6.2, SWJ7.2, U10.8 (GND), U10.15 (~CE), U11.8 (GND), U11.15 (~CE), U12.8 (GND), U12.15 (~CE); also elsewhere on the board
unnamed: R64.1, SWG8.1, U10.11 (D0)
unnamed: R65.1, SWG7.1, U10.12 (D1)
unnamed: R66.1, SWG6.1, U10.13 (D2)
unnamed: R67.1, SWG5.1, U10.14 (D3)
unnamed: R68.1, SWG4.1, U10.3 (D4)
unnamed: R69.1, SWG3.1, U10.4 (D5)
unnamed: R70.1, SWG2.1, U10.5 (D6)
unnamed: R71.1, SWG1.1, U10.6 (D7)
unnamed: R72.1, SWH4.1, U11.11 (D0)
unnamed: R73.1, SWH3.1, U11.12 (D1)
unnamed: R74.1, SWH2.1, U11.13 (D2)
unnamed: R75.1, SWH1.1, U11.14 (D3)
unnamed: R76.1, U11.3 (D4)
unnamed: R77.1, SWH7.1, U11.4 (D5)
unnamed: R78.1, SWH6.1, U11.5 (D6)
unnamed: R79.1, SWH5.1, U11.6 (D7)
unnamed: R80.1, U12.11 (D0)
unnamed: R81.1, SWJ3.1, U12.12 (D1)
unnamed: R82.1, SWJ2.1, U12.13 (D2)
unnamed: R83.1, SWJ7.1, U12.14 (D3)
unnamed: R84.1, SWJ4.1, U12.3 (D4)
unnamed: R85.1, SWJ1.1, U12.4 (D5)
unnamed: R86.1, SWJ6.1, U12.5 (D6)
unnamed: R87.1, SWJ5.1, U12.6 (D7)
unnamed: R88.2, U12.7 (~Q7)
SW_CP: J4.2, U10.2 (CP), U11.2 (CP), U12.2 (CP); also elsewhere on the board
SW_DO6: U10.10 (DS); also elsewhere on the board
SW_DO9: R88.1; also elsewhere on the board
~SW_PL: J4.3, U10.1 (~PL), U11.1 (~PL), U12.1 (~PL); also elsewhere on the board

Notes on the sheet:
Source termination short

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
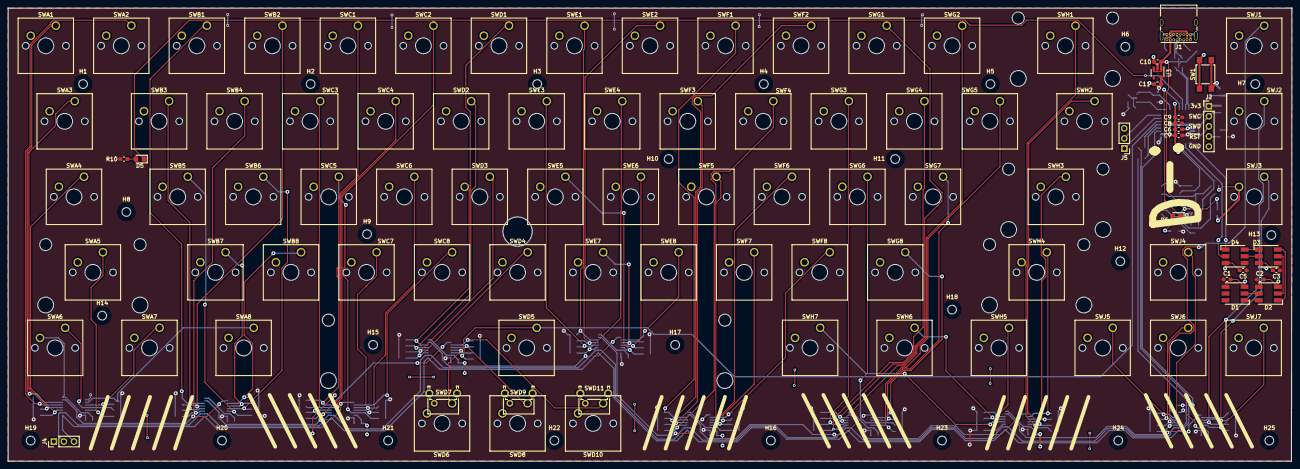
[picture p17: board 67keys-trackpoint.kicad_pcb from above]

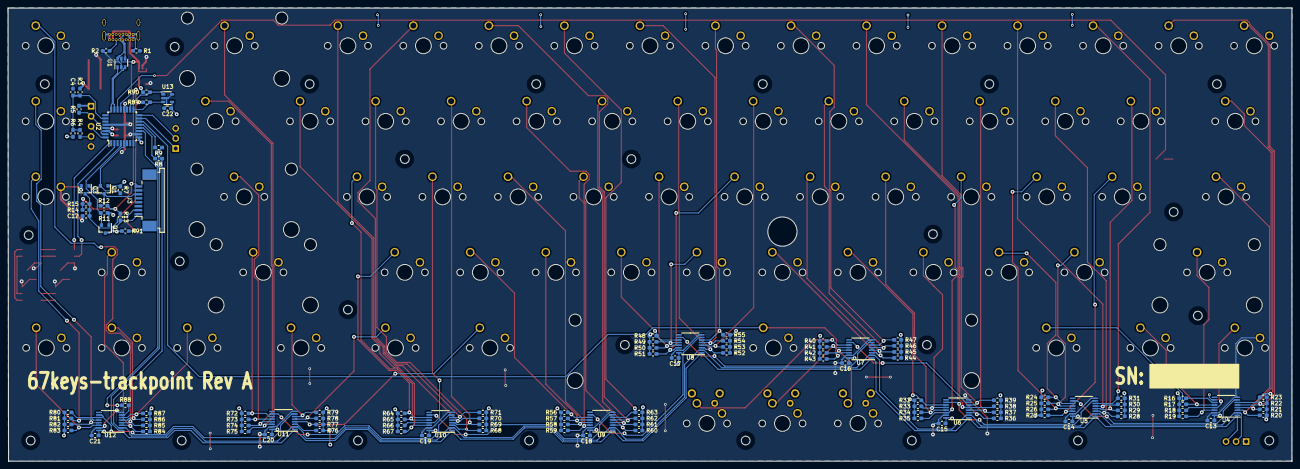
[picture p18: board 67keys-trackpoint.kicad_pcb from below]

Board: 2 copper layers, 323.9 x 114.3 mm, 239 parts (118 on the bottom side), 122 nets.

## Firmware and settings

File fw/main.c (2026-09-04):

/*
 * Copyright (c) 2016-2017, Alex Taradov <alex@taradov.com>
 * All rights reserved.
 *
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
 * THIS SOFTWARE IS PROVIDED BY THE COPYRIGHT HOLDERS AND CONTRIBUTORS "AS IS"
 * AND ANY EXPRESS OR IMPLIED WARRANTIES, INCLUDING, BUT NOT LIMITED TO, THE
 * IMPLIED WARRANTIES OF MERCHANTABILITY AND FITNESS FOR A PARTICULAR PURPOSE
 * ARE DISCLAIMED. IN NO EVENT SHALL THE COPYRIGHT HOLDER OR CONTRIBUTORS BE
 * LIABLE FOR ANY DIRECT, INDIRECT, INCIDENTAL, SPECIAL, EXEMPLARY, OR
 * CONSEQUENTIAL DAMAGES (INCLUDING, BUT NOT LIMITED TO, PROCUREMENT OF
 * SUBSTITUTE GOODS OR SERVICES; LOSS OF USE, DATA, OR PROFITS; OR BUSINESS
 * INTERRUPTION) HOWEVER CAUSED AND ON ANY THEORY OF LIABILITY, WHETHER IN
 * CONTRACT, STRICT LIABILITY, OR TORT (INCLUDING NEGLIGENCE OR OTHERWISE)
 * ARISING IN ANY WAY OUT OF THE USE OF THIS SOFTWARE, EVEN IF ADVISED OF THE
 * POSSIBILITY OF SUCH DAMAGE.
 */

/*- Includes ----------------------------------------------------------------*/
#include <stdlib.h>
#include "samd21.h"
#include "hal_gpio.h"
#include "nvm_data.h"
#include "tusb.h"
#include "usb_descriptors.h"
#include "led.h"
#include "spi_master.h"
#include "matrix.h"
#include "keymap.h"
#include "config.h"
#include "trackpoint.h"

/*- Definitions -------------------------------------------------------------*/

HAL_GPIO_PIN(TEST, A, 14)
HAL_GPIO_PIN(TESTMID, A, 15) // TODO: DEBUG

/*- Implementations ---------------------------------------------------------*/

volatile uint32_t msticks = 0;

void SysTick_Handler(void)
{
	msticks++;
}

uint32_t millis(void)
{
	return msticks;
}

void delay_us(uint32_t us)
{
	if (!us || (us >= SysTick->LOAD))
		return;
	if(!(SysTick->CTRL & SysTick_CTRL_ENABLE_Msk))
		return;
	us = F_CPU/1000000*us;
	uint32_t time = SysTick->VAL;
	while ((time - SysTick->VAL) < us);
}

void delay_ms(uint32_t ms)
{
	uint32_t tempms = millis();
	while((millis() - tempms) < ms);
}

//-----------------------------------------------------------------------------
static void sys_init(void)
{

	NVMCTRL->CTRLB.bit.RWS = 1; // Set Flash Wait States to 1 for 3.3V operation @ 48MHz

	SYSCTRL->DFLLCTRL.reg = 0; // See Errata 9905
	while (0 == (SYSCTRL->PCLKSR.reg & SYSCTRL_PCLKSR_DFLLRDY)); // Wait for DFLL sync complete

	SYSCTRL->DFLLMUL.reg = SYSCTRL_DFLLMUL_MUL(48000); // Set to multiply USB SOF frequency (when USB attached)

	uint32_t coarse, fine;
	coarse = NVM_READ_CAL(DFLL48M_COARSE_CAL); // Read factory cals for DFLL48M
	//fine = NVM_READ_CAL(DFLL48M_FINE_CAL);
	fine = 0xA; // D21 Fam Datasheet table 37-64 note 1
	SYSCTRL->DFLLVAL.reg = SYSCTRL_DFLLVAL_COARSE(coarse) | SYSCTRL_DFLLVAL_FINE(fine); // Load factory cals

	SYSCTRL->DFLLCTRL.reg = SYSCTRL_DFLLCTRL_ENABLE | 
		SYSCTRL_DFLLCTRL_USBCRM | // Set DFLL for USB Clock Recovery Mode
		//SYSCTRL_DFLLCTRL_BPLCKC | // Bypass Coarse Lock, ignored with USBCRM
		SYSCTRL_DFLLCTRL_CCDIS |  // Disable Chill Cycle
		SYSCTRL_DFLLCTRL_RUNSTDBY |  // Run during standby for USB wakeup interrupts
		SYSCTRL_DFLLCTRL_MODE;   // Set Closed Loop Mode
		//SYSCTRL_DFLLCTRL_STABLE; // Fine calibration register locks (stable) after fine lock, ignored with USBCRM

	while (!(SYSCTRL->PCLKSR.reg & SYSCTRL_PCLKSR_DFLLRDY)); // Wait for DFLL sync complete

	//Setup Generic Clock Generator 0 with DFLL48M as source:
	GCLK->GENCTRL.reg = GCLK_GENCTRL_ID(0) |
		GCLK_GENCTRL_SRC(GCLK_SOURCE_DFLL48M) |
		GCLK_GENCTRL_IDC |
		//GCLK_GENCTRL_RUNSTDBY | // Only has an effect with output enabled
		GCLK_GENCTRL_GENEN;
	while (GCLK->STATUS.reg & GCLK_STATUS_SYNCBUSY);

	// Set up GCLK1 as output from DFLL48M w/divider TODO: DEBUG
	HAL_GPIO_TESTMID_pmuxen(PORT_PMUX_PMUXE_H);
	GCLK->GENCTRL.reg = GCLK_GENCTRL_ID(1) | GCLK_GENCTRL_SRC(GCLK_SOURCE_DFLL48M) |
		GCLK_GENCTRL_RUNSTDBY |
		GCLK_GENCTRL_OE |
		GCLK_GENCTRL_GENEN;
	GCLK->GENDIV.reg = GCLK_GENDIV_ID(1) | GCLK_GENDIV_DIV(4800);
	while (GCLK->STATUS.reg & GCLK_STATUS_SYNCBUSY);

	//Disable OSC8M and generator 2 (enabled by UF2 bootloader)
	GCLK->GENCTRL.reg = GCLK_GENCTRL_ID(2);
	GCLK->GENCTRL.bit.GENEN = 0;
	SYSCTRL->OSC8M.bit.ENABLE = 0;

	SysTick_Config(48000); //systick at 1ms
}

void usb_setup(void)
{
	// Enable USB Clocks
	PM->APBBMASK.reg |= PM_APBBMASK_USB;
	PM->AHBMASK.reg |= PM_AHBMASK_USB;
	GCLK->CLKCTRL.reg = GCLK_CLKCTRL_CLKEN | GCLK_CLKCTRL_ID(USB_GCLK_ID) |
		GCLK_CLKCTRL_GEN(0);

	// Enable USB pins
	PORT->Group[0].PINCFG[PIN_PA24G_USB_DM].bit.PMUXEN = 1;
	PORT->Group[0].PMUX[PIN_PA24G_USB_DM/2].reg &= ~(0xF << (4 * (PIN_PA24G_USB_DM & 0x01u)));
	PORT->Group[0].PMUX[PIN_PA24G_USB_DM/2].reg |= MUX_PA24G_USB_DM << (4 * (PIN_PA24G_USB_DM & 0x01u));
	PORT->Group[0].PINCFG[PIN_PA25G_USB_DP].bit.PMUXEN = 1;
	PORT->Group[0].PMUX[PIN_PA25G_USB_DP/2].reg &= ~(0xF << (4 * (PIN_PA25G_USB_DP & 0x01u)));
	PORT->Group[0].PMUX[PIN_PA25G_USB_DP/2].reg |= MUX_PA25G_USB_DP << (4 * (PIN_PA25G_USB_DP & 0x01u));
}

void USB_Handler(void) {
  dcd_int_handler(0);
}

//-----------------------------------------------------------------------------
// Invoked when usb bus is suspended
// remote_wakeup_en : if host allow us	to perform remote wakeup
// Within 7ms, device must draw an average of current less than 2.5 mA from bus
void tud_suspend_cb(bool remote_wakeup_en)
{
	(void) remote_wakeup_en;

	led_off();

	/* Enable spacebar interrupt, disable systick, and go to sleep
	 * EIC setup and EIC_Handler are in trackpoint.c */
	EIC->INTENSET.reg = EIC_INTENSET_EXTINT11; // Enable spacebar interrupt
	EIC->CONFIG[0].bit.SENSE4 = EIC_CONFIG_SENSE4_LOW_Val; //TP_CLK

	// delay_ms(2);

	SysTick->CTRL &= ~(SysTick_CTRL_ENABLE_Msk); // Disable systick
	// PM->SLEEP.reg |= PM_SLEEP_IDLE(2);	// Set idle
	//SCB->SCR |= SCB_SCR_SLEEPDEEP_Msk;	// Set deep sleep, not working

	__WFI();

	SysTick->CTRL |= SysTick_CTRL_ENABLE_Msk; // Enable systick
}

// Invoked when usb bus is resumed
void tud_resume_cb(void)
{
	led_on();
}

//--------------------------------------------------------------------+
// USB CDC
//--------------------------------------------------------------------+

// Invoked when cdc when line state changed e.g connected/disconnected
void tud_cdc_line_state_cb(uint8_t itf, bool dtr, bool rts)
{
	(void) itf;

	// connected
	if ( dtr && rts )
	{
		// print initial message when connected
		tud_cdc_write_str("67key config\n\n");

		while (!tud_cdc_write_flush())
			tud_task();
	}

	//Reset into bootloader when baud is 1200 and dtr unasserted
	if (!dtr) {
		cdc_line_coding_t lc;
		tud_cdc_get_line_coding(&lc);
		if (lc.bit_rate == 1200) {
			unsigned long *a = (unsigned long *)(HMCRAMC0_ADDR + HMCRAMC0_SIZE - 4); // Make a boot key at end of RAM
			*a = 0xf01669ef; // Set boot key to uf2 magic value
			NVIC_SystemReset();
		}
	}
}

//-----------------------------------------------------------------------------
/* Retrieves full line from cdc, returns true when found */
uint8_t cdc_task(char line[], uint8_t max)
{
	static uint8_t pos = 0;
	uint8_t success = 0;

	if (tud_cdc_connected() && tud_cdc_available()) {	// connected and there are data available
		uint8_t buf[64];
		uint8_t count = tud_cdc_read(buf, sizeof(buf));

		for (uint8_t i=0; i<count; i++) {
			tud_cdc_write_char(buf[i]);
			if (pos <= max-1) {
				if ((line[pos] = buf[i]) == '\n')
					success = 1;
				pos++;
			}
			else // Reset count if over max length
				pos = 0;
		}
		while (!tud_cdc_write_flush())
			tud_task();
	}


	if (success) {
		success = 0;
		line[pos] = '\0';
		pos = 0;
		return 1;
	}
	else
		return 0;
}

void cdc_write_num(int num, uint8_t radix)
{
	char s[25];
	itoa(num, s, radix);
	tud_cdc_write_str(s);
}

const char help_msg[] = \
						"b [0-255]		board led brightness"\
						"d			Enable debug output"\
						"r			Read sensistivity from tp module"
						"w [0-255]		Write sensitivity to tp module";

//--------------------------------------------------------------------+
// USB HID
//--------------------------------------------------------------------+

void hid_task(void)
{
	const uint8_t btn = shift_task();

	/*------------- Mouse -------------*/

	if (btn || tp_reportAvailable()) 
	{
		uint8_t mousekeys = 0;
		uint8_t fn_key = 0;
		struct tp_DataReport tpdata = {0,0,0};

		// Only try to send report if data is available
		if (read_mousekeys(&mousekeys, &fn_key) || tp_reportAvailable()) {
			if (tp_reportAvailable())
				tpdata = tp_getStreamReport();

			// Make sure we can send
			while( !tud_hid_ready() ) {
				tud_task();
			}

			if (config.debug) {
				if ( mousekeys ) {
					tud_cdc_write_str("mousekeys: 0b");
					cdc_write_num(mousekeys, 2);
					tud_cdc_write_char('\n');
				}
				if ( tpdata.x || tpdata.y ) {
					tud_cdc_write_str("mouse x: ");
					cdc_write_num(tpdata.x, 10);
					tud_cdc_write_str("\nmouse y: ");
					cdc_write_num(tpdata.y, 10);
					tud_cdc_write_char('\n');
				}

				while (!tud_cdc_write_flush())
					tud_task();
			}

			static uint8_t middle_last = 0;
			static uint8_t middle_move = 0;
			if ((mousekeys & MOUSE_BUTTON_MIDDLE) && !fn_key && (tpdata.x || tpdata.y)) { // Scroll if middle mouse pressed and movement
				if (tpdata.x >= config.scrolllim)
					tpdata.x = 1;
				else if (tpdata.x <= -config.scrolllim)
					tpdata.x = -1;
				else
					tpdata.x = 0;

				if (tpdata.y >= config.scrolllim)
					tpdata.y = 1;
				else if (tpdata.y <= -config.scrolllim)
					tpdata.y = -1;
				else
					tpdata.y = 0;

				if ( tpdata.x || tpdata.y ) {
					if (config.scrollswapxy)
						tud_hid_mouse_report(REPORT_ID_MOUSE, (mousekeys & ~MOUSE_BUTTON_MIDDLE), 0, 0, tpdata.x/config.scrollscaley, tpdata.y/config.scrollscalex);
					else
						tud_hid_mouse_report(REPORT_ID_MOUSE, (mousekeys & ~MOUSE_BUTTON_MIDDLE), 0, 0, tpdata.y/config.scrollscaley, tpdata.x/config.scrollscalex);
				}

				//Register as a move even if we only moved under scrolllim
				middle_move = 1;
				middle_last = 1;
			}
			else if ((mousekeys & MOUSE_BUTTON_MIDDLE) && !fn_key && !middle_move && !middle_last) { // send other button state if just pressed and no movement, wait for release
				tud_hid_mouse_report(REPORT_ID_MOUSE, (mousekeys & ~MOUSE_BUTTON_MIDDLE), 0, 0, 0, 0);
				middle_last = 1;
			}
			else if (!(mousekeys & MOUSE_BUTTON_MIDDLE) && !fn_key && middle_move && middle_last) { // just moved, send other keys
				tud_hid_mouse_report(REPORT_ID_MOUSE, mousekeys, 0, 0, 0, 0);
				middle_move = 0;
				middle_last = 0;
			}
			else if (!(mousekeys & MOUSE_BUTTON_MIDDLE) && !fn_key && !middle_move && middle_last) { // didn't move, press and release key
				tud_hid_mouse_report(REPORT_ID_MOUSE, (mousekeys | MOUSE_BUTTON_MIDDLE), 0, 0, 0, 0);
				while( !tud_hid_ready() )
					tud_task();
				tud_hid_mouse_report(REPORT_ID_MOUSE, mousekeys, 0, 0, 0, 0);
				middle_last = 0;
			}
			else {	// regular move or Fn pressed for middle drag
				if (config.swapxy)
					tud_hid_mouse_report(REPORT_ID_MOUSE, mousekeys, tpdata.y/config.scalex, tpdata.x/config.scaley, 0, 0);
				else
					tud_hid_mouse_report(REPORT_ID_MOUSE, mousekeys, tpdata.x/config.scalex, tpdata.y/config.scaley, 0, 0);
			}
		}
	} //if (btn || tp_reportAvailable()) 

	/*------------- Keyboard -------------*/

	if ( btn )
	{
		uint8_t keycode[6] = { 0 };
		uint8_t modifiers = 0;
		uint8_t change = 0;

		// only send report if data available
		change |= read_keys(keycode); 
		change |= read_modifiers(&modifiers);
		if (change) {
			// Make sure we can send
			while( !tud_hid_ready() ) {
				tud_task();
			}

			tud_hid_keyboard_report(REPORT_ID_KEYBOARD, modifiers, keycode);

			if (config.debug) {
				tud_cdc_write_str("Mods: ");
				cdc_write_num(modifiers, 2);
				tud_cdc_write_str("\nCodes:");
				for(uint8_t i = 0; i < 6; i++) {
					tud_cdc_write_char('\t');
					cdc_write_num(keycode[i], 10);
				}
				tud_cdc_write_char('\n');

				while (!tud_cdc_write_flush())
					tud_task();
			}
		}
	}

	/*------------- Consumer -------------*/

	if ( btn ) {
		uint16_t key = 0;
		if (read_consumer(&key)) {
			// Make sure we can send
			while( !tud_hid_ready() ) {
				tud_task();
			}

			tud_hid_report(REPORT_ID_CONSUMER, &key, sizeof(key));
			if (config.debug) {
				tud_cdc_write_str("Consumer: 0x");
				cdc_write_num(key, 16);
				tud_cdc_write_char('\n');

				while (!tud_cdc_write_flush())
					tud_task();
			}
		}
	}
}

// Invoked when received GET_REPORT control request
// Application must fill buffer report's content and return its length.
// Return zero will cause the stack to STALL request
uint16_t tud_hid_get_report_cb(uint8_t itf, uint8_t report_id, hid_report_type_t report_type, uint8_t* buffer, uint16_t reqlen)
{
	// TODO not Implemented
	(void) itf;
	(void) report_id;
	(void) report_type;
	(void) buffer;
	(void) reqlen;

	return 0;
}

// Invoked when received SET_REPORT control request or
// received data on OUT endpoint ( Report ID = 0, Type = 0 )
void tud_hid_set_report_cb(uint8_t itf, uint8_t report_id, hid_report_type_t report_type, uint8_t const* buffer, uint16_t bufsize)
{
	(void) itf;
	(void) report_id;
	(void) report_type;
	(void) bufsize;

	led_update(buffer[1]);
}

//-----------------------------------------------------------------------------
int main(void)
{
	sys_init();
	config_init();
	rgb_init();
	usb_setup();
	tp_init(); // stalls for >1sec, place before usb
	tusb_init();
	spi_init(2000000, 0);

	HAL_GPIO_TEST_out();

	char s[25];

	while (1)
	{
		HAL_GPIO_TEST_toggle(); // TODO: DEBUG

		tud_task();
		hid_task();
		led_task();

		if (cdc_task(s, 25)) {
			if (s[0] == 'b') {
				uint32_t ms = atoi((const char *)&s[1]);
				if (ms > 0 && ms < 50000) {
					led_brightness(ms);
				}
			} else if (s[0] == 'd') {
				config.debug = !config.debug;
				cdc_write_num(config.debug, 10);
				tud_cdc_write_char('\n');
			} else if (s[0] == 'R') {
				tp_forceRecal();
			} else if (s[0] == 'r') {
				cdc_write_num(tp_readFromRamLocation(0x4a), 10);
				tud_cdc_write_char('\n');
			} else if (s[0] == 'w') {
				uint32_t sens = atoi((const char *)&s[1]);
				tp_setSensitivityFactor(sens);
				tud_cdc_write_char('1');

			} else if (s[0] == 'x') {
				tud_cdc_write_char(config_check_eep_version());
				tud_cdc_write_char('\n');
			} else if (s[0] == 'c') {
				tud_cdc_write_char(config_check_default_version());
				tud_cdc_write_char('\n');
			} else if (s[0] == 'o') {
				if(!config_write_eeprom()) {
					tud_cdc_write_str("0\n");
				}
				else {
					tud_cdc_write_str("1\n");
				}
			} else if (s[0] == 'i') {
				if (!config_read_eeprom()) {
					tud_cdc_write_str("0\n");
				}
				else {
					tud_cdc_write_str("1\n");
				}
			} else if (s[0] == 'y') {
				config_load_defaults();
				tud_cdc_write_str("1\n");
			} else if (s[0] == 'l') {
				if (s[1] == 'r') {
					cdc_write_num(config.scrolllim, 10);
					tud_cdc_write_char('\n');
				}
				else if (s[1] == 'w') {
					uint8_t i = atoi((const char *)&s[2]);
					config.scrolllim = i;
					tud_cdc_write_str("1\n");
				}
			}

			while (!tud_cdc_write_flush())
				tud_task();
		}
	}

	return 0;
}

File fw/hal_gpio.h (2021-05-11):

/*
 * Copyright (c) 2014-2016, Alex Taradov <alex@taradov.com>
 * All rights reserved.
 *
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
 * THIS SOFTWARE IS PROVIDED BY THE COPYRIGHT HOLDERS AND CONTRIBUTORS "AS IS"
 * AND ANY EXPRESS OR IMPLIED WARRANTIES, INCLUDING, BUT NOT LIMITED TO, THE
 * IMPLIED WARRANTIES OF MERCHANTABILITY AND FITNESS FOR A PARTICULAR PURPOSE
 * ARE DISCLAIMED. IN NO EVENT SHALL THE COPYRIGHT HOLDER OR CONTRIBUTORS BE
 * LIABLE FOR ANY DIRECT, INDIRECT, INCIDENTAL, SPECIAL, EXEMPLARY, OR
 * CONSEQUENTIAL DAMAGES (INCLUDING, BUT NOT LIMITED TO, PROCUREMENT OF
 * SUBSTITUTE GOODS OR SERVICES; LOSS OF USE, DATA, OR PROFITS; OR BUSINESS
 * INTERRUPTION) HOWEVER CAUSED AND ON ANY THEORY OF LIABILITY, WHETHER IN
 * CONTRACT, STRICT LIABILITY, OR TORT (INCLUDING NEGLIGENCE OR OTHERWISE)
 * ARISING IN ANY WAY OUT OF THE USE OF THIS SOFTWARE, EVEN IF ADVISED OF THE
 * POSSIBILITY OF SUCH DAMAGE.
 */

#ifndef _HAL_GPIO_H_
#define _HAL_GPIO_H_

/*- Definitions -------------------------------------------------------------*/
#define HAL_GPIO_PORTA       0
#define HAL_GPIO_PORTB       1
#define HAL_GPIO_PORTC       2

#define HAL_GPIO_PMUX_A      0
#define HAL_GPIO_PMUX_B      1
#define HAL_GPIO_PMUX_C      2
#define HAL_GPIO_PMUX_D      3
#define HAL_GPIO_PMUX_E      4
#define HAL_GPIO_PMUX_F      5
#define HAL_GPIO_PMUX_G      6
#define HAL_GPIO_PMUX_H      7
#define HAL_GPIO_PMUX_I      8

#define HAL_GPIO_PIN(name, port, pin)						\
  static inline void HAL_GPIO_##name##_set(void)				\
  {										\
    PORT->Group[HAL_GPIO_PORT##port].OUTSET.reg = (1 << pin);			\
    (void)HAL_GPIO_##name##_set;						\
  }										\
										\
  static inline void HAL_GPIO_##name##_clr(void)				\
  {										\
    PORT->Group[HAL_GPIO_PORT##port].OUTCLR.reg = (1 << pin);			\
    (void)HAL_GPIO_##name##_clr;						\
  }										\
										\
  static inline void HAL_GPIO_##name##_toggle(void)				\
  {										\
    PORT->Group[HAL_GPIO_PORT##port].OUTTGL.reg = (1 << pin);			\
    (void)HAL_GPIO_##name##_toggle;						\
  }										\
										\
  static inline void HAL_GPIO_##name##_write(int value)				\
  {										\
    if (value)									\
      PORT->Group[HAL_GPIO_PORT##port].OUTSET.reg = (1 << pin);			\
    else									\
      PORT->Group[HAL_GPIO_PORT##port].OUTCLR.reg = (1 << pin);			\
    (void)HAL_GPIO_##name##_write;						\
  }										\
										\
  static inline void HAL_GPIO_##name##_in(void)					\
  {										\
    PORT->Group[HAL_GPIO_PORT##port].DIRCLR.reg = (1 << pin);			\
    PORT->Group[HAL_GPIO_PORT##port].PINCFG[pin].reg |= PORT_PINCFG_INEN;	\
    (void)HAL_GPIO_##name##_in;							\
  }										\
										\
  static inline void HAL_GPIO_##name##_out(void)				\
  {										\
    PORT->Group[HAL_GPIO_PORT##port].DIRSET.reg = (1 << pin);			\
    PORT->Group[HAL_GPIO_PORT##port].PINCFG[pin].reg |= PORT_PINCFG_INEN;	\
    (void)HAL_GPIO_##name##_out;						\
  }										\
										\
  static inline void HAL_GPIO_##name##_pullen(int state)			\
  {										\
    if (state)									\
      PORT->Group[HAL_GPIO_PORT##port].PINCFG[pin].reg |= PORT_PINCFG_PULLEN;	\
    else									\
      PORT->Group[HAL_GPIO_PORT##port].PINCFG[pin].reg &= ~PORT_PINCFG_PULLEN;	\
    (void)HAL_GPIO_##name##_pullen;						\
  }										\
										\
  static inline int HAL_GPIO_##name##_read(void)				\
  {										\
    return (PORT->Group[HAL_GPIO_PORT##port].IN.reg & (1 << pin)) != 0;		\
    (void)HAL_GPIO_##name##_read;						\
  }										\
										\
  static inline int HAL_GPIO_##name##_state(void)				\
  {										\
    return (PORT->Group[HAL_GPIO_PORT##port].DIR.reg & (1 << pin)) != 0;	\
    (void)HAL_GPIO_##name##_state;						\
  }										\
										\
  static inline void HAL_GPIO_##name##_pmuxen(int mux)				\
  {										\
    PORT->Group[HAL_GPIO_PORT##port].PINCFG[pin].reg |= PORT_PINCFG_PMUXEN;	\
    if (pin & 1)								\
      PORT->Group[HAL_GPIO_PORT##port].PMUX[pin>>1].bit.PMUXO = mux;		\
    else									\
      PORT->Group[HAL_GPIO_PORT##port].PMUX[pin>>1].bit.PMUXE = mux;		\
    (void)HAL_GPIO_##name##_pmuxen;						\
  }										\
										\
  static inline void HAL_GPIO_##name##_pmux_set(int mux)				\
  {										\
    if (pin & 1)								\
      PORT->Group[HAL_GPIO_PORT##port].PMUX[pin>>1].bit.PMUXO = mux;		\
    else									\
      PORT->Group[HAL_GPIO_PORT##port].PMUX[pin>>1].bit.PMUXE = mux;		\
    (void)HAL_GPIO_##name##_pmux_set;						\
  }										\
										\
  static inline void HAL_GPIO_##name##_pmux_toggle(void)				\
  {										\
    PORT->Group[HAL_GPIO_PORT##port].PINCFG[pin].reg ^= PORT_PINCFG_PMUXEN;	\
    (void)HAL_GPIO_##name##_pmux_toggle;						\
  }										\
										\
  static inline void HAL_GPIO_##name##_pmuxdis(void)				\
  {										\
    PORT->Group[HAL_GPIO_PORT##port].PINCFG[pin].reg &= ~PORT_PINCFG_PMUXEN;	\
    (void)HAL_GPIO_##name##_pmuxdis;						\
  }										\

#endif // _HAL_GPIO_H_

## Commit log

2020-06-10 Initial commit. Mostly complete.
    [67keys-trackpoint.kicad_pcb, 67keys-trackpoint.sch, key_matrix.sch]
2020-06-10 Added bypass caps to Dotstars
    [67keys-trackpoint.sch]
2020-06-11 Added check note, removed sch-bak from index
    [67keys-trackpoint.sch]
2020-06-11 Change symbol for USB connnector
    [67keys-trackpoint.sch]
2020-06-12 Run DotStart at 3.3V, add notes
    [67keys-trackpoint.sch]
2020-06-12 Completed usb-c
    [67keys-trackpoint.sch]
2020-06-12 Annotated, key matrix named after columns/rows
    [67keys-trackpoint.sch, key_matrix.sch]
2020-06-12 Assigned footprints
    [67keys-trackpoint.sch, key_matrix.sch]
2020-06-12 Layout: board outline, keys, some diodes
    [67keys-trackpoint.kicad_pcb]
2020-06-12 Partial layout
    [67keys-trackpoint.kicad_pcb, 67keys-trackpoint.sch, key_matrix.sch]
2020-06-13 Almost fully routed, total mess.
    - 10x7 matrix, shuffled around
    [67keys-trackpoint.kicad_pcb, 67keys-trackpoint.sch]
2020-06-13 Changed to 14x5 matrix, removed LED
    [67keys-trackpoint.kicad_pcb, 67keys-trackpoint.sch, key_matrix.sch]
2020-06-13 Laid out most diodes. Switched Row 4 and tpclk
    [67keys-trackpoint.kicad_pcb, 67keys-trackpoint.sch]
2020-06-13 Moved and named APA lines
    [67keys-trackpoint.kicad_pcb, 67keys-trackpoint.sch]
2020-06-13 Updated some design rules
    [67keys-trackpoint.kicad_pcb]
2020-06-13 Routed. Very ugly.
    [67keys-trackpoint.kicad_pcb]
2020-06-13 Added cuttable jumper to SWD line
    [67keys-trackpoint.kicad_pcb, 67keys-trackpoint.sch]
2020-06-13 Added notes
    [67keys-trackpoint.kicad_pcb, 67keys-trackpoint.sch]
2020-06-14 Added tp hole, notes, started footprint
    [67keys-trackpoint.kicad_pcb]
2020-06-14 Added alternat footprints for mouse buttons
    [67keys-trackpoint.kicad_pcb, key_matrix.sch]
2020-06-14 Added some mounting holes
    [67keys-trackpoint.kicad_pcb]
2020-06-14 Moved some references
    [67keys-trackpoint.kicad_pcb]
2020-06-15 Started matrix schematic
    [67keys-trackpoint.kicad_pcb, 67keys-trackpoint.sch, key_matrix.sch]
2020-06-15 Cleared tracks from pcm
    [67keys-trackpoint.kicad_pcb]
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2020-06-16 Laid out schematic keys
    [67keys-trackpoint.kicad_pcb, 67keys-trackpoint.sch, key_matrix1.sch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]
2020-06-17 Finished schematic
    - Laid out shift matrix
    - Added series termination resistors to shift spi
    - Changed label for TP_RESET, should be active high.
    [67keys-trackpoint.sch, key_matrix1.sch, key_matrix2.sch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]
2020-06-17 Reannotated pcb keys according to schematic
    [67keys-trackpoint.kicad_pcb, 67keys-trackpoint.sch, key_matrix1.sch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]
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2020-06-19 Added mounting holes to schematic
    [67keys-trackpoint.sch, key_matrix1.sch, key_matrix2.sch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]
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2020-06-19 Started routing, switched TP pins
    [67keys-trackpoint.kicad_pcb, 67keys-trackpoint.sch]
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2020-06-19 Changed termination resistors to 100 ohm.
    [67keys-trackpoint.kicad_pcb, 67keys-trackpoint.sch, key_matrix3.sch]
2020-06-19 Changed eeprom part number
    [67keys-trackpoint.kicad_pcb, 67keys-trackpoint.sch]
2020-06-19 Moved references, updated readme
    [67keys-trackpoint.kicad_pcb]
2020-06-20 Made trackpoint virtual footprints
    [67keys-trackpoint.kicad_pcb]
2020-06-20 Mount tp module horizontally, moved mounting hole
    [67keys-trackpoint.kicad_pcb]
2020-06-20 Moved some tracks and mounting holes, clearance
    [67keys-trackpoint.kicad_pcb]
2020-06-20 Added extra pin header, some artwork
    [67keys-trackpoint.kicad_pcb, 67keys-trackpoint.sch]
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2020-06-20 Added back board design
    [67keys-trackpoint_back_board-B_Cu.gbr, 67keys-trackpoint_back_board-B_Mask.gbr, 67keys-trackpoint_back_board-B_SilkS.gbr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]
2020-06-20 Locked keys and mounting holes
    [67keys-trackpoint.kicad_pcb]
2020-06-20 Tied to 3v3 first input to shift regs, U4-10
    [67keys-trackpoint.kicad_pcb, key_matrix1.sch]
2020-06-20 Added some artwork, changed a track
    [67keys-trackpoint.kicad_pcb]
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2020-06-21 Adjusted filled areas, moved led trace
    [67keys-trackpoint.kicad_pcb]
2020-06-21 Added direct line to space bar. Stitched some planes
    [67keys-trackpoint.kicad_pcb, 67keys-trackpoint.sch, key_matrix2.sch]
2020-06-21 Tweaked drawings, updated page descriptions
    [67keys-trackpoint.kicad_pcb, 67keys-trackpoint.sch, key_matrix1.sch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]
2020-06-21 Tweaked artwork, added SN field
    [67keys-trackpoint.kicad_pcb]
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2020-06-22 Shifted usb connector, removed derp
    [67keys-trackpoint.kicad_pcb]
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2020-06-23 Made Rev A PCB
    [67keys-trackpoint-B_Cu.gbr, 67keys-trackpoint-B_Mask.gbr, 67keys-trackpoint-B_SilkS.gbr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]
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2020-07-03 Trackpoint working, still glitchy
    [config.c, main.c, trackpoint.c]
2020-07-04 Added code to set TP sensitivity, buggy
    [config.c, main.c, trackpoint.c]
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2020-07-05 Misc changes, reduce TP reset, increase spi speed
    [config.c, led.c, main.c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]
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2020-07-08 Fixed LED during sleep. Edit todos, add specs.
    [led.c]
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2020-08-02 Fixed stalling on tp_data* functions
    - tp\_getDataBit was hanging up on mix between commands and stream mode.
    Set up a timeout in interrupt.
    - Reworked tp\_getDataBit().
    - set sensitivity on start up.
    - changed config structure to initialize at definition.
    [config.c, main.c, trackpoint.c]
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2020-08-07 Eeprom storage working
    - automatically load settings on start up.
    - Haven't set up i2c error checks
    - version control in config
    - left floats in i2c init
    [config.c, i2c_master.c, i2c_master.h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]
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2020-08-14 Fixed cdc write busy waiting, debug printing.
    [main.c, matrix.c]
2020-08-15 Try to only send report if key is pressed, buggy.
    Need to check if there was a change, not just if something was pressed.
    Sometimes zero reports are necessary.
    [main.c]
2021-05-08 Change C89,C90 to 4.7k
    [67keys-trackpoint.sch]
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2021-05-11 Moved to fw/ with git-filter-repo, fixed submodule
2025-11-28 Clean up hw/, remove plots from index
    [67keys-trackpoint-B_Cu.gbr, 67keys-trackpoint-B_Mask.gbr, 67keys-trackpoint-B_SilkS.gbr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]
2025-11-28 Convert to Kicad 9
    [67keys-trackpoint.kicad_pcb, 67keys-trackpoint.kicad_sch, 67keys-trackpoint_back_board.kicad_pcb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]
2026-08-23 Update files to Kicad 10
    [67keys-trackpoint.kicad_pcb, 67keys-trackpoint.kicad_sch, 67keys-trackpoint_back_board.kicad_pcb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]
2026-09-04 Fix regex string in uf2conv
    [uf2conv.py]
